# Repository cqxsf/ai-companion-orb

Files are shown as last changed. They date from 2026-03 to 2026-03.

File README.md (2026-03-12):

# AI Companion Orb 🔮

> 有温度的家庭 IoT 伴侣 —— 陪伴、守护、连接

一个 85mm 球形 AI 陪伴设备，用灯光呼吸、触摸互动和语音对话，为独居老人和远程照护家庭提供情感陪伴与安全守护。

## 项目结构

```
ai-companion-orb/
├── firmware/          ← ESP32-S3 固件 (ESP-IDF + C)
│   ├── main/          ← 主程序入口
│   ├── components/    ← 功能组件
│   │   ├── led_engine/     ← WS2812B 灯光引擎
│   │   ├── touch_sensor/   ← 电容触摸检测
│   │   ├── audio/          ← 麦克风 + 扬声器
│   │   ├── wifi_manager/   ← WiFi 连接管理
│   │   ├── ble_provision/  ← BLE 配网
│   │   └── ota/            ← OTA 升级
│   └── test/
├── app/               ← Flutter 移动端 App
│   └── lib/
│       ├── core/           ← 主题、路由、常量
│       ├── features/       ← 功能模块
│       ├── models/         ← 数据模型
│       ├── services/       ← API / BLE / 推送
│       └── widgets/        ← 通用组件
├── backend/           ← 云端服务 (Node.js / Python)
│   └── src/
│       ├── routes/         ← API 路由
│       ├── services/       ← 业务逻辑 (LLM对话/记忆等)
│       ├── models/         ← 数据库模型
│       └── middleware/     ← 认证/限流
├── hardware/          ← 硬件设计文件
│   ├── 3d_models/     ← OpenSCAD / STL 文件
│   ├── pcb/           ← KiCad PCB 设计
│   └── bom/           ← BOM 清单
├── docs/              ← 项目文档
└── scripts/           ← 构建/部署/工具脚本
```

## 硬件规格 (Orb v1)

| 参数 | 规格 |
|---|---|
| 主控 | ESP32-S3-WROOM-1 (N16R8) |
| 外径 | 85mm 球形 |
| LED | WS2812B × 12 (RGB, 环形) |
| 麦克风 | INMP441 × 3 (I2S, 120°均布) |
| 扬声器 | 40mm 4Ω 3W + MAX98357A |
| 触摸 | 电容触摸 (ESP32-S3 内置) |
| IMU | BMI270 |
| 电池 | 2000mAh 锂电 |
| 连接 | WiFi 2.4GHz + BLE 5.0 |
| 外壳 | PC 半透明扩散球壳 + 硅胶底座 |
| 售价目标 | ¥699 |
| BOM 成本 | ≈ ¥261 (@10k) |

## 技术栈

- **固件**: ESP-IDF v5.x + FreeRTOS (C)
- **App**: Flutter 3.x + Dart
- **后端**: Python FastAPI / Node.js
- **AI**: DashScope (通义千问) / DeepSeek API
- **数据库**: PostgreSQL + Redis
- **推送**: 极光推送 / Firebase

## 快速开始

```bash
# 固件开发
cd firmware && idf.py set-target esp32s3 && idf.py build

# App 开发
cd app && flutter pub get && flutter run

# 后端开发
cd backend && pip install -r requirements.txt && uvicorn src.main:app --reload
```

## 品牌定位

> **「有温度的家庭 IoT」**
> 不是冷冰冰的智能硬件，而是家庭成员级的 AI 存在。

## License

MIT

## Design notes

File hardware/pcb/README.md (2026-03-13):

# Orb V8 PCB — KiCad 工程

> ESP32-S3 核心，55mm 圆形 4 层板，适配 Ø98mm × H68mm 球壳内腔。

---

## 工程文件结构

```
hardware/pcb/
├── README.md                    ← 本文件
├── orb_main.kicad_pro           ← KiCad 工程文件
├── schematics/
│   ├── main.kicad_sch           ← MCU + 电源入口总图
│   ├── power.kicad_sch          ← 充电管理 (TP4056 + DW01 + ME6211)
│   ├── audio.kicad_sch          ← 麦克风阵列 (4× INMP441) + 功放 (MAX98357A)
│   ├── led.kicad_sch            ← LED 驱动 (16+8 WS2812B, GPIO18)
│   └── sensor.kicad_sch         ← BME280 + MPU6050 I2C 传感器
├── layout/
│   ├── orb_main.kicad_pcb       ← PCB 布局 (55mm 圆形)
│   └── orb_main.kicad_dru       ← DRC 规则文件
├── fabrication/
│   ├── gerbers/                 ← 生产 Gerber 文件（导出后放此处）
│   └── bom.csv                  ← 物料清单
└── datasheets/                  ← 关键器件规格书（PDF）
```

---

## 层叠结构（4 层板，1.6mm）

| 层 | 功能 | 说明 |
|----|---|---|
| L1 Top Signal | 信号线 + 器件面 | ESP32-S3、传感器、麦克风在此 |
| L2 GND | 地平面 | 完整铺铜，屏蔽 EMI |
| L3 3.3V Power | 电源平面 | 3.3V LDO 输出覆铜 |
| L4 Bottom Signal | 信号线 + 焊盘 | LED 驱动线、部分去耦电容 |

---

## GPIO 引脚分配（V8 最终版）

| GPIO | 功能 | 器件 | 备注 |
|---|---|---|---|
| GPIO1 | I2S_SPK_BCLK | MAX98357A | 扬声器 I2S Bit Clock |
| GPIO2 | I2S_SPK_LRC | MAX98357A | 扬声器 I2S LR Clock |
| GPIO3 | I2S_SPK_DIN | MAX98357A | 扬声器 I2S Data |
| GPIO4 | I2S_MIC_BCLK | 4× INMP441 | 麦克风 I2S Bit Clock |
| GPIO5 | I2S_MIC_LRCK | 4× INMP441 | 麦克风 I2S LR Clock |
| GPIO6 | I2S_MIC_DATA | 4× INMP441 | 麦克风 I2S Data (并联输出) |
| GPIO8 | I2C_SDA | BME280 + MPU6050 | I2C 数据线 (4.7kΩ 上拉) |
| GPIO9 | I2C_SCL | BME280 + MPU6050 | I2C 时钟线 (4.7kΩ 上拉) |
| GPIO18 | LED_DIN | 16+8 WS2812B | RMT 输出，330Ω 串联保护 |
| TOUCH1~3 | 触摸区域 | ESP32-S3 内置 | 上/中/下 3 个触摸感应极板 |

> 扬声器 I2S（GPIO1/2/3）与麦克风 I2S（GPIO4/5/6）使用**独立 I2S 总线**，避免回声。

---

## 电源链设计

```
USB-C (5V)
  │
  ▼
TP4056 充电管理
  ├── Rprog = 1.2kΩ → 充电电流 1000mA
  ├── CHRG LED (红): 充电中
  └── STDBY LED (绿): 充电完成
        │
        ▼
    18650 锂电池 (3.7V nominal)
        │
    DW01 + 8205A 保护电路
  ├── 过充保护 (>4.25V 截止)
  ├── 过放保护 (<2.4V 截止)
  └── 短路保护
        │
        ▼
    ME6211 LDO (3.3V / 500mA)
  ├── 输入电容: 10µF
  ├── 输出电容: 22µF
  └── 3.3V 给 ESP32-S3 + 传感器
        
LED 独立 5V 轨道
  ├── 从 USB 或升压模块供 5V
  ├── 主滤波: 1000µF 电解
  ├── 去耦: 100nF × LED区domain
  └── 每颗 WS2812B 串 33Ω 限流
```

---

## 布局关键规则

### RF 约束
- ESP32-S3 天线（FCC 认证 PCB 天线）必须伸出 PCB 边缘
- 天线底部及两侧 5mm 范围内**禁止铺铜**（包括地平面开窗）
- 天线附近避免高速信号线

### 麦克风布局
- 4× INMP441 以 90° 间隔均匀环形排列在 PCB 中轴外圈
- 每个麦克风正上方的外壳对应一个 Ø1.5mm 拾音孔
- 麦克风与功放（MAX98357A）相互隔离，避免声学耦合

### LED 走线
- GPIO18 → 330Ω 保护电阻 → 主灯环 LED1 DIN
- 主灯环 16 颗首尾菊链：DOUT(n) → DIN(n+1)
- Halo 8 颗从主灯环 DOUT(16) 继续菊链
- LED 5V 引脚旁置 100nF 去耦电容
- 总 5V 主滤波 1000µF 电解电容靠近 USB 输入端

### I2C 总线
- SDA/SCL 线长尽量短，避免过孔
- 总线末端 4.7kΩ 上拉至 3.3V
- BME280 和 MPU6050 地址不冲突（BME280: 0x76/0x77，MPU6050: 0x68/0x69）

---

## BOM 清单（V8 主要器件）

| 位号 | 器件 | 封装 | 数量 | 单价(¥) | 备注 |
|---|---|---|---|---|---|
| U1 | ESP32-S3-WROOM-1 | SMD | 1 | ¥25 | 16MB Flash / 8MB PSRAM |
| U2 | TP4056 | SOT23-6 | 1 | ¥0.5 | 1A 充电管理 |
| U3 | ME6211 | SOT23-3 | 1 | ¥0.3 | 3.3V 500mA LDO |
| U4 | DW01A | SOT23-6 | 1 | ¥0.3 | 电池保护 IC |
| Q1 | 8205A | DFN-8 | 1 | ¥0.5 | 双 MOS 保护管 |
| U5 | MAX98357A | WLCSP-9 | 1 | ¥8 | I2S DAC + D类功放 |
| U6~U9 | INMP441 | LGA-6 | 4 | ¥6×4 | MEMS I2S 麦克风 |
| U10 | BME280 | LCC-8 | 1 | ¥8 | 温湿度+气压传感器 |
| U11 | MPU6050 | QFN-24 | 1 | ¥5 | 六轴 IMU |
| LED1~16 | WS2812B | 5050 | 16 | ¥0.5×16 | 主灯环 |
| LED17~24 | WS2812B | 5050 | 8 | ¥0.5×8 | 底部 Halo |
| R1 | 330Ω | 0402 | 1 | ¥0.02 | LED DIN 保护 |
| R2 | 1.2kΩ | 0402 | 1 | ¥0.02 | TP4056 Rprog (1A) |
| R3,R4 | 4.7kΩ | 0402 | 2 | ¥0.02 | I2C 上拉 |
| C1 | 1000µF/10V | 电解 | 1 | ¥0.5 | LED 主滤波 |
| C2 | 10µF | 0805 | 1 | ¥0.1 | LDO 输入滤波 |
| C3 | 22µF | 0805 | 1 | ¥0.1 | LDO 输出滤波 |
| C4~C28 | 100nF | 0402 | 25 | ¥0.02 | 去耦 (各 IC 旁) |
| J1 | USB-C 16P | SMD | 1 | ¥1.5 | 充电 + 调试 |
| BAT1 | 18650 | 通孔 | 1 | ¥15 | 3.7V 2600mAh |
| SP1 | 4Ω 3W | SMD | 1 | ¥5 | 扬声器 |

**BOM 估算总成本：约 ¥120-140（含 PCB 打样 5 片分摊）**

---

## 开发状态

- [ ] KiCad 原理图（5 张子图）
- [ ] PCB 布局布线（55mm 圆形）
- [ ] DRC 通过（0 错误）
- [ ] Gerber 导出验证
- [ ] PCB 打样（嘉立创/JLCPCB）
- [ ] 首批焊板验证

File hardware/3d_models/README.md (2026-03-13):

# Orb 3D 模型 — 硬件结构设计

> 从概念到量产的结构迭代

## 版本演进

| 版本 | 目录 | 核心特征 |
|---|---|---|
| V2 | `modules/` + `orb_v2_assembly.scad` | 5 层模块、扩散腔、基础声学 |
| **V4** | **`orb_v4/`** | **光导环、倒相管、工业比例、免支撑打印** |

**当前主力版本: V4**

---

## V4 总体参数

| 参数 | 数值 | 设计依据 |
|---|---|---|
| 直径 | 92 mm | 桌面设备最佳尺寸 |
| 高度 | 75 mm | 黄金比例 0.82 × 直径 |
| 壁厚 | 2.2 mm | 注塑级壁厚 |
| 底面 | Ø62 mm | 桌面稳定性 |
| LED | 24× WS2812B | Ø60mm 环形 |
| 扬声器 | 40mm 4Ω 3W | 共振腔 + 倒相管 |
| 电池 | 18650 | 单节 3.7V |
| 麦克风 | 3× INMP441 | 120° 均布 |

---

## V4 文件结构

```
orb_v4/
├── orb_config.scad         ← 全局参数（改这里调尺寸）
├── orb_assembly.scad       ← 主入口（F5 预览 / F6 渲染）
├── orb_shell_top.scad      ← 上壳（扩散球壳）
├── orb_shell_middle.scad   ← 中框（结构骨架）
├── orb_shell_bottom.scad   ← 底座（声孔 + USB-C）
├── orb_lightguide.scad     ← 光导环（核心光学件）
├── orb_led_mount.scad      ← LED PCB 安装环
├── orb_acoustic.scad       ← 声学腔 + 倒相管
├── orb_pcb_mount.scad      ← PCB 支撑柱 (M2)
├── orb_mic_array.scad      ← 麦克风阵列安装座
├── orb_battery.scad        ← 18650 电池槽
└── exports/                ← STL 导出目录
```

---

## V4 三大核心升级

### 1. LED 光导环 (Light Guide Ring)

```
V2: LED → 扩散腔(12mm) → 二次扩散片 → 球壳    （仍有颗粒感）
V4: LED → 光导环(壁厚6mm) → 球壳               （连续光带）
```

- 光导壁厚 6mm，全内反射混合光线
- LED 入光槽精确对位 24 颗 WS2812B
- 效果接近 Apple HomePod / Google Nest

### 2. 倒相管声学 (Bass Reflex)

```
┌─────────────┐
│   扬声器     │  40mm 4Ω 3W
├─────────────┤
│  共振腔      │  ~25cc 容积
├──┐     ┌───┤
│  │倒相管│   │  Ø8 × 12mm
└──┘     └───┘
     ↓ 底座声孔
```

- 调谐频率 ~120Hz，低频增强 ~40%，声压级 +3dB

### 3. 免支撑打印

| 部件 | 材料 | 支撑 |
|---|---|---|
| 上壳 | Translucent PLA | 无 |
| 中框 | PLA+ | 无 |
| 底座 | PLA+ | 无 |
| 光导环 | Translucent PLA | 无 |

---

## 使用方法

### OpenSCAD 环境验证

已在 Apple Silicon macOS 上验证以下安装结果：

- OpenSCAD 版本：2025.05.16
- 安装路径：`/Applications/OpenSCAD.app`
- 命令行入口：`/opt/homebrew/bin/openscad`
- 二进制架构：universal binary（包含 arm64，可原生运行于 M1/M2/M3）

可用以下命令复核本机安装：

```bash
file /Applications/OpenSCAD.app/Contents/MacOS/OpenSCAD
/opt/homebrew/bin/openscad --version
```

### 预览装配体

1. OpenSCAD 打开 `orb_v4/orb_assembly.scad`
2. F5 预览 / `EXPLODE = 15;` 爆炸视图 / `SECTION = true;` 剖面

也可直接从命令行启动 GUI：

```bash
open -a /Applications/OpenSCAD.app hardware/3d_models/orb_v4/orb_assembly.scad
```

### 导出 STL

1. 设置 `PRINT_PART = "top";`（或 `"mid"` / `"bottom"` / `"lightguide"`）
2. F6 渲染 → 导出 STL → 保存到 `exports/`

也可用命令行直接导出：

```bash
mkdir -p hardware/3d_models/orb_v4/exports

/opt/homebrew/bin/openscad -o hardware/3d_models/orb_v4/exports/top.stl \
     -D 'PRINT_PART="top"' hardware/3d_models/orb_v4/orb_assembly.scad

/opt/homebrew/bin/openscad -o hardware/3d_models/orb_v4/exports/mid.stl \
     -D 'PRINT_PART="mid"' hardware/3d_models/orb_v4/orb_assembly.scad

/opt/homebrew/bin/openscad -o hardware/3d_models/orb_v4/exports/bottom.stl \
     -D 'PRINT_PART="bottom"' hardware/3d_models/orb_v4/orb_assembly.scad

/opt/homebrew/bin/openscad -o hardware/3d_models/orb_v4/exports/lightguide.stl \
     -D 'PRINT_PART="lightguide"' hardware/3d_models/orb_v4/orb_assembly.scad
```

建议优先导出这 4 个打印件：上壳、中框、底座、光导环。

### 修改尺寸

编辑 `orb_v4/orb_config.scad`，所有模块自动更新。

---

## 拓竹打印配置

| 参数 | 设置 |
|---|---|
| 层高 | 0.2 mm |
| 外壁 | 3 层 |
| 填充 | 15% |
| 支撑 | **无** (免支撑设计) |
| 温度 | 210°C / 热床 60°C |

---

## V5 升级方向

| 特性 | 描述 |
|---|---|
| 热管理 | ESP32 散热通道 |
| 磁吸外壳 | 免螺丝装配 |
| 声学罩 | 麦克风降噪微结构 |
| 微纹理 | 扩散壳内壁消除颗粒感 |
| 触摸区域 | 电容触摸铜箔定位 |

---

## V2 (旧版，保留参考)

V2 文件位于根目录 `modules/` + `orb_v2_assembly.scad`，5 层模块结构。详见各文件注释。

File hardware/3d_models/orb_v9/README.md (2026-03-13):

# Orb V9 — 工业设计级 3D 模型

> 从"概念球体"到"可量产桌面情绪物件"的跨越。

---

## 核心设计参数

| 参数 | V8 | **V9** | 改进 |
|---|----|---|---|
| 直径 | Ø98mm | **Ø112mm** | 更有桌面存在感 |
| 高度 | 68mm | **86mm** | 内部空间更充裕 |
| 比例 H/W | 0.69 | **0.77** | 蛋形，不像音箱 |
| 曲面 | 三段拼接 | **连续椭球** | 完全无拼接感 |
| 顶盖 | 光扩散罩 | **浮岛结构** | 0.6mm 缝隙=呼吸口 |
| 灯环 | 可见灯带 | **隐藏扩散罩** | 光从内部自然透出 |
| 零件数 | 7+ | **5** | 装配更简单 |

---

## 椭球方程

$$\left(\frac{x}{56}\right)^2 + \left(\frac{z}{43}\right)^2 = 1$$

绕 Z 轴旋转生成完整椭球体，曲率从顶部到底部连续过渡，无断层。

---

## 5 件式结构（剖面图）

```
      ╭──────╮          ← Top_Cap (浮岛顶盖 Ø92×6mm)
    ╭─╯ 0.6mm╰─╮       ← 缝隙（麦克风孔 + 灯光溢出）
  ╭─╯            ╰─╮
 │    Shell_Top     │   ← 上壳（椭球上半）
 │                  │
 ├── LED_Ring ──────┤   ← 灯环扩散罩（4mm 磨砂 PC）
 │                  │
 │   Shell_Bottom   │   ← 下壳（椭球下半 + 螺丝柱）
  ╰─╮            ╭─╯
    ╰──────────╯
      ┗━Base━┛          ← 底盖（Ø62×3mm + 硅胶防滑垫）
```

---

## 文件结构

### FreeCAD 版本（推荐，参数化可修改）
| 文件 | 说明 |
|---|---|
| `orb_v9_config.py` | 全局参数定义（Python） |
| `orb_v9_freecad.py` | FreeCAD 建模主脚本（一键生成 5 零件） |

### OpenSCAD 版本（与 V4-V8 工具链兼容）
| 文件 | 说明 |
|---|---|
| `orb_config.scad` | 全局参数 + `v9_r(z)` 椭球函数 |
| `orb_shell.scad` | 椭球壳体模块 |
| `orb_shell_top.scad` | 上壳 |
| `orb_shell_bottom.scad` | 下壳（带螺丝柱） |
| `orb_led_ring.scad` | LED 灯环扩散罩 |
| `orb_top_cap.scad` | 浮岛顶盖（带麦克风孔） |
| `orb_base.scad` | 底盖（带防滑垫定位槽） |
| `orb_assembly.scad` | 装配预览（支持爆炸视图） |
| `export_stl.sh` | 一键 STL 导出脚本 |

---

## 内部空间布局

```
┌───────────────────────┐ ← 顶部 12mm
│     麦克风板 (4×INMP441)│
├───────────────────────┤
│                       │
│    主控 PCB (55mm)     │ ← 中部 38mm
│    ESP32-S3           │
│                       │
├───────────────────────┤
│    18650 电池          │ ← 底部 36mm
│    扬声器 (MAX98357A)  │
└───────────────────────┘
```

---

## 快速开始

### FreeCAD 建模
```bash
# 1. 安装 FreeCAD
brew install --cask freecad

# 2. 在 FreeCAD 中执行
# Macro → Execute Macro → orb_v9_freecad.py
# 自动生成 5 个零件 + 导出 STL
```

### OpenSCAD 导出
```bash
cd hardware/3d_models/orb_v9
bash export_stl.sh
```

---

## 3D 打印参数

| 参数 | 壳体 | 灯环 |
|---|---|---|
| 材料 | PLA | 透明 PETG |
| 层高 | 0.2mm | 0.2mm |
| 填充 | 15% | 100%（透光需要） |
| 支撑 | 上壳内部 | 无 |
| 壁数 | 3 | 2 |

---

## 装配说明

1. **下壳 + 底盖** → M2×6 螺丝 ×4 从底部固定
2. **LED 灯环** → 卡入下壳上沿环形槽
3. **上壳** → 扣合到灯环上沿（环形卡扣）
4. **顶盖** → 浮放于上壳顶部（0.6mm 自然缝隙）
5. 测试：灯环亮起后，光线应从缝隙和灯环均匀透出

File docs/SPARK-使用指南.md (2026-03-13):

# AI Companion Orb — 完整架构提示词

> 本提示词供 SPARK / Copilot / Claude 等 AI 编程代理使用
> 使用方式：在 SPARK 中打开本项目，AI 会自动读取 CLAUDE.md 获取架构约束

## 给 SPARK 的使用说明

1. 打开 `ai-companion-orb` 项目
2. SPARK 会自动读取 `CLAUDE.md` 作为项目上下文
3. 按 Phase 0 优先级开始开发（灯光引擎 → 触摸 → 音频 → WiFi → 对话闭环）

## 第一个任务建议

对 SPARK 说：

```
请阅读 CLAUDE.md，然后从 Phase 0 开始：
实现 firmware/components/led_engine/ 灯光引擎组件。

要求：
1. 基于 ESP-IDF v5.2 RMT 驱动
2. 24 颗 WS2812B RGB LED 环形排列（V2 升级）
3. 实现 CLAUDE.md 中定义的 9 种情绪灯光模式
4. 呼吸灯参数：3.5s 周期 / sine 曲线 / 5%-40% 亮度
5. 所有灯光切换有 200-500ms 渐变过渡
6. 提供 orb_led_init() 和 orb_led_set_mood() 接口
7. 组件必须有 CMakeLists.txt 和 README.md
```

---

## Orb V4 硬件结构设计（量产级）

### 版本演进

| 版本 | 直径 | 高度 | LED | 光学 | 声学 | 状态 |
|---|---|---|-----|---|---|---|
| V1 | 85mm | — | 12 | 直射 | 无 | 概念 |
| V2 | 90mm | 78mm | 24 | 扩散腔 | 密封腔 | 原型 |
| **V4** | **92mm** | **75mm** | **24** | **光导环** | **倒相管** | **当前** |

### 工业设计比例

```
高度 = 直径 × 0.82 → 75mm = 92mm × 0.82
```

消费电子黄金比例，视觉效果最佳。

### 五层模块架构

```
┌──────────────────────────────┐
│  ① 扩散球壳 (Translucent PLA) │  球面上壳，光线均匀散射
├──────────────────────────────┤
│  ② LED 光导环                 │  壁厚 6mm，全反射导光
│     + LED PCB 安装环           │  24× WS2812B, Ø60mm
├──────────────────────────────┤
│  ③ 中框 (结构骨架)             │  承载 PCB, 麦克风拾音孔
│     主控 PCB Ø65mm            │  ESP32-S3 + 3× INMP441
│     3 点 120° M2 固定         │
├──────────────────────────────┤
│  ④ 声学模块 (倒相音箱)         │  40mm 扬声器 + 共振腔
│     共振腔 ~25cc              │  倒相管 Ø8×12mm
│     调谐频率 ~120Hz           │  低频 +40%, +3dB
├──────────────────────────────┤
│  ⑤ 底座 + 电源                │  18650 电池 + USB-C
│     底面 Ø62mm               │  声孔 + 倒相口 + 硅胶垫
└──────────────────────────────┘
```

### 三大核心升级 (V2→V4)

**1. 光导环** — LED 光线经光导体全内反射混合，消灭 LED 颗粒感
```
V2: LED → 扩散腔 → 扩散片 → 球壳  （仍可见光斑）
V4: LED → 光导环(6mm壁厚) → 球壳  （连续均匀光带）
```

**2. 倒相管** — 声学腔体背波相位反转，低频增强 40%
```
扬声器 → 共振腔(25cc) → 倒相管(Ø8×12mm) → 底座声孔
```

**3. 免支撑打印** — 三件式分模，拓竹无需支撑，成功率极高

### 3D 模型文件 (V4)

```
hardware/3d_models/orb_v4/
├── orb_config.scad          ← 全局参数（改尺寸只改这里）
├── orb_assembly.scad        ← 主入口（F5 预览 / F6 渲染）
├── orb_shell_top.scad       ← 上壳（扩散球壳）
├── orb_shell_middle.scad    ← 中框（结构骨架 + 麦克风孔）
├── orb_shell_bottom.scad    ← 底座（声孔 + USB-C + 硅胶垫）
├── orb_lightguide.scad      ← 光导环（核心光学件）
├── orb_led_mount.scad       ← LED PCB 安装环
├── orb_acoustic.scad        ← 声学腔 + 倒相管
├── orb_pcb_mount.scad       ← PCB 支撑柱 (3点 M2)
├── orb_mic_array.scad       ← 麦克风阵列安装座
├── orb_battery.scad         ← 18650 电池槽
└── exports/                 ← STL 导出（打印用）
```

### OpenSCAD 安装与验证

当前开发环境已验证可用：

- OpenSCAD: 2025.05.16
- 安装路径: `/Applications/OpenSCAD.app`
- CLI 路径: `/opt/homebrew/bin/openscad`
- 架构: universal binary，包含 arm64，可原生运行于 Apple Silicon

安装校验命令：

```bash
file /Applications/OpenSCAD.app/Contents/MacOS/OpenSCAD
/opt/homebrew/bin/openscad --version
```

预期结果：二进制信息包含 `arm64`，版本输出为 `OpenSCAD version 2025.05.16`。

### V4 预览与 STL 导出

打开 GUI 预览：

```bash
open -a /Applications/OpenSCAD.app hardware/3d_models/orb_v4/orb_assembly.scad
```

推荐预览方式：

1. 打开 `hardware/3d_models/orb_v4/orb_assembly.scad`
2. 使用 F5 快速预览整体装配
3. 设置 `EXPLODE = 15;` 查看爆炸图
4. 设置 `SECTION = true;` 检查内部剖面

命令行导出 STL：

```bash
mkdir -p hardware/3d_models/orb_v4/exports

/opt/homebrew/bin/openscad -o hardware/3d_models/orb_v4/exports/top.stl \
	-D 'PRINT_PART="top"' hardware/3d_models/orb_v4/orb_assembly.scad

/opt/homebrew/bin/openscad -o hardware/3d_models/orb_v4/exports/mid.stl \
	-D 'PRINT_PART="mid"' hardware/3d_models/orb_v4/orb_assembly.scad

/opt/homebrew/bin/openscad -o hardware/3d_models/orb_v4/exports/bottom.stl \
	-D 'PRINT_PART="bottom"' hardware/3d_models/orb_v4/orb_assembly.scad

/opt/homebrew/bin/openscad -o hardware/3d_models/orb_v4/exports/lightguide.stl \
	-D 'PRINT_PART="lightguide"' hardware/3d_models/orb_v4/orb_assembly.scad
```

已验证 `top`、`bottom`、`lightguide` 可正常导出，其中 `lightguide` 的非流形警告已修正。

### 拓竹打印配置

| 参数 | 设置 |
|---|---|
| 材料 | PLA+（结构）/ Translucent PLA（上壳 + 光导环） |
| 层高 | 0.2 mm |
| 外壁 | 3 层 |
| 填充 | 15% |
| 支撑 | **无**（免支撑设计） |
| 温度 | 210°C / 热床 60°C |
| 分件 | 上壳 / 中框 / 底座 / 光导环 分别打印 |

### V5 升级方向

1. **热管理** — ESP32 散热通道设计
2. **磁吸外壳** — 免螺丝磁吸装配
3. **声学罩** — 麦克风降噪微结构
4. **微纹理** — 扩散壳内壁消除最后的颗粒感

---

## 后续任务队列

| 序号 | 任务 | 对 SPARK 的指令 |
|---|---|---|
| 1 | 灯光引擎 | "实现 led_engine 组件，24 颗 LED，参考 CLAUDE.md §四" |
| 2 | 触摸检测 | "实现 touch_sensor 组件，参考 CLAUDE.md §五" |
| 3 | 音频录放 | "实现 audio 组件，参考 CLAUDE.md §六" |
| 4 | WiFi 管理 | "实现 wifi_manager 组件，处理连接/重连/状态上报" |
| 5 | BLE 配网 | "实现 ble_provision 组件，参考 CLAUDE.md §八" |
| 6 | 主程序 | "实现 main/app_main.c，整合所有组件，用事件驱动" |
| 7 | 3D 外壳 V4 | "优化 hardware/3d_models/orb_v4/ 中的 OpenSCAD 模型" |
| 8 | 后端 API | "实现 FastAPI 后端，参考 CLAUDE.md §九" |
| 9 | Flutter App | "实现 Flutter App 配网流程，参考 CLAUDE.md §八" |
| 10 | 对话闭环 | "实现完整对话链路：唤醒→录音→STT→LLM→TTS→播放" |

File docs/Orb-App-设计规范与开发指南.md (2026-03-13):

# AI Companion Orb App — 全方位 UI 设计规范与 Flutter 开发指南

> 版本: v1.0 | 2026-03-13 | 输出者: 小墨 (uidesigner)
> 工程仓库: `cqxsf/ai-companion-orb` → `app/` 目录
> 设计灵魂: **「不解决效率，只解决孤独」—— 每一帧都有生命力**

---

## 一、产品定位与设计哲学

### 1.1 核心用户

| 角色 | 主场景 | App 入口频率 | 设计目标 |
|---|---|---|---|
| 独居青年 (主用户) | 情感对话 / 查看 Orb 状态 | 每天 3-10 次 | 感受到被陪伴 |
| 独居老人 | 被照护 + 与 Orb 对话 | 被动（Orb主动发起） | 极简、温暖 |
| 远程家属 (子女端) | 查看老人与 Orb 互动状态 | 每天 1-3 次 | 安心、可远程关怀 |

### 1.2 设计三原则

1. **存在感** — 每一帧都有生命力（光 / 动 / 色），App 打开即感受 Orb 「在」
2. **情绪可见** — 颜色 = 情绪，用户无需读字就能感知 Orb 的内心状态
3. **陪伴感** — 界面设计本身就是陪伴行为，不是工具界面

### 1.3 与 LifeGuardian 的区别

| 维度 | LifeGuardian | Orb App |
|---|---|---|
| 设计灵魂 | 放心吧（安全/理性） | 我在（情感/感性） |
| 首屏 | AI安心语（文字驱动） | Orb光球（视觉驱动） |
| 色系 | 5状态色（功能色） | 7情绪色（情感色） |
| 背景 | 微暖蓝白 | 沉浸深色（Orb发光） |
| 文案 | 行为描述 | AI感知文案 |
| 交互 | 信息浏览为主 | 对话+情感互动 |

---

## 二、信息架构

### 2.1 Tab 结构 (4 Tab)

```
AI Companion Orb App
├── 🌙 Orb (Home)           ← 默认首页
│   ├── Orb 光球主视觉（全屏沉浸）
│   ├── 当前情绪状态文字
│   ├── AI 感知问候语
│   ├── 今日记忆摘要（2-3条）
│   └── "和 Orb 聊聊" 快捷入口
│
├── 💬 对话 (Chat)
│   ├── 情感对话界面
│   ├── 情绪实时转场（气泡颜色变化）
│   └── 低压退出选项
│
├── 📖 记忆 (Memory)
│   ├── Bento 记忆相册（情感日记）
│   ├── 情绪标签筛选
│   ├── 情感趋势图
│   └── "Orb 记得的事"
│
└── ⚙️ 设置 (Settings)
    ├── Orb 设备管理（固件/WiFi/LED）
    ├── 个性化（性格/声音/称呼）
    ├── 家庭连接（Orb-to-Orb/家庭成员）
    ├── 隐私（记忆删除/数据导出）
    └── 关于
```

### 2.2 页面清单

| # | 页面 | 类型 | 优先级 |
|---|---|---|---|
| P1 | Orb 首页（光球+情绪） | Tab-首页 | P0 |
| P2 | 对话页 | Tab-聊天 | P0 |
| P3 | 记忆相册 | Tab-记忆 | P1 |
| P4 | 记忆详情 | 二级页面 | P1 |
| P5 | 设置主页 | Tab-设置 | P1 |
| P6 | Orb 个性化 | 二级页面 | P1 |
| P7 | BLE 配网 | 流程页面 | P0 |
| P8 | 家庭连接 | 二级页面 | P2 |
| P9 | 情感趋势 | 二级页面 | P2 |
| P10 | 子女端远程关怀 | 二级页面 | P1 |

---

## 三、颜色系统 (Design Token)

### 3.1 设计决策：沉浸深色优先

Orb App 与成前云/LifeGuardian 最大的区别：**默认深色主题，Orb 光球是唯一光源。**

设计灵感：Oura Ring (奢侈品调性) + Apple Activity Rings (信息即可视化)

### 3.2 Layer 2 — Orb 专属色

```dart
/// Orb 情绪色系 — 7种情绪 × 2模式
class OrbColors {
  // ══════════════════════════════════════
  //  7 情绪色（产品灵魂）
  // ══════════════════════════════════════

  // ── 平静陪伴（默认状态）──
  static const Color calm = Color(0xFF6366F1);           // 柔和紫蓝
  static const Color calmLight = Color(0xFF818CF8);      // 浅紫
  static const Color calmGlow = Color(0x4D6366F1);       // 发光

  // ── 喜悦活力 ──
  static const Color joy = Color(0xFFF59E0B);            // 温暖琥珀金
  static const Color joyLight = Color(0xFFFBBF24);
  static const Color joyGlow = Color(0x4DF59E0B);

  // ── 关怀温柔 ──
  static const Color care = Color(0xFFEC4899);            // 玫瑰粉
  static const Color careLight = Color(0xFFF472B6);
  static const Color careGlow = Color(0x4DEC4899);

  // ── 专注聆听 ──
  static const Color listen = Color(0xFF10B981);          // 翡翠绿
  static const Color listenLight = Color(0xFF34D399);
  static const Color listenGlow = Color(0x4D10B981);

  // ── 担忧感知 ──
  static const Color concern = Color(0xFF3B82F6);         // 深海蓝
  static const Color concernLight = Color(0xFF60A5FA);
  static const Color concernGlow = Color(0x4D3B82F6);

  // ── 兴奋期待 ──
  static const Color excited = Color(0xFFEF4444);         // 活力红
  static const Color excitedLight = Color(0xFFF87171);
  static const Color excitedGlow = Color(0x4DEF4444);

  // ── 困倦休眠 ──
  static const Color sleep = Color(0xFF1E293B);           // 深夜黑
  static const Color sleepLight = Color(0xFF334155);
  static const Color sleepGlow = Color(0x1A1E293B);

  // ══════════════════════════════════════
  //  界面色（沉浸深色优先）
  // ══════════════════════════════════════

  // ── 背景层 ──
  static const Color bgBase = Color(0xFF0A0A0F);          // 接近纯黑（OLED友好）
  static const Color bgCard = Color(0xFF12121A);           // 卡片深色
  static const Color bgElevated = Color(0xFF1A1A25);       // 抬升层
  static const Color bgOverlay = Color(0xFF252530);        // hover/选中

  // ── 边框层（发光代替阴影）──
  static const Color borderSubtle = Color(0x14FFFFFF);     // 6% white
  static const Color borderActive = Color(0x26FFFFFF);     // 15% white

  // ── 文字层 ──
  static const Color textPrimary = Color(0xF2FFFFFF);      // 95% white
  static const Color textSecondary = Color(0x99FFFFFF);    // 60% white
  static const Color textTertiary = Color(0x59FFFFFF);     // 35% white
  static const Color textMuted = Color(0xFF94A3B8);        // Slate-400

  // ── 亮色模式（可选，不是主推）──
  static const Color lightBgBase = Color(0xFFFAFAFF);
  static const Color lightBgCard = Color(0xFFFFFFFF);
  static const Color lightTextPrimary = Color(0xFF1E293B);
  static const Color lightTextSecondary = Color(0xFF64748B);

  // ══════════════════════════════════════
  //  功能色（最小集合，不抢情绪色）
  // ══════════════════════════════════════
  static const Color success = Color(0xFF22C55E);
  static const Color warning = Color(0xFFFBBF24);
  static const Color error = Color(0xFFF87171);
  static const Color offline = Color(0xFF64748B);
}
```

### 3.3 情绪 → 颜色映射表

| 情绪 | 颜色 | Orb 光效 | App 背景 | 气泡/组件颜色 | 触发场景 |
|---|---|---|---|---|---|
| 平静陪伴 | calm #6366F1 | 柔和紫呼吸 4s | 深紫渐变 | 紫色半透明 | 默认/日常 |
| 喜悦活力 | joy #F59E0B | 金色脉冲 | 暖金渐变 | 琥珀半透明 | 用户开心/分享喜事 |
| 关怀温柔 | care #EC4899 | 玫瑰粉柔光 | 粉色晕染 | 玫瑰半透明 | Orb表达关心 |
| 专注聆听 | listen #10B981 | 翡翠绿稳定 | 深绿渐变 | 翠绿半透明 | 用户在说话 |
| 担忧感知 | concern #3B82F6 | 深蓝缓动 | 深蓝渐变 | 蓝色半透明 | 感知用户负面情绪 |
| 兴奋期待 | excited #EF4444 | 红色跳跃 | 红色渐变 | 红色半透明 | 激动/惊喜场景 |
| 困倦休眠 | sleep #1E293B | 极暗缓熄 | 近黑背景 | 深灰半透明 | 深夜/用户疲惫 |

### 3.4 情绪转场规则

```dart
/// 情绪色转场规范
class OrbEmotionTransition {
  // 转场时长 & 曲线
  static const Map<String, Duration> durations = {
    'calm_to_care':    Duration(milliseconds: 1200),  // ease-in-out
    'calm_to_joy':     Duration(milliseconds: 600),   // bounceOut
    'calm_to_concern': Duration(milliseconds: 2000),  // linear (深沉)
    'any_to_sleep':    Duration(milliseconds: 3000),  // ease-in (缓熄)
    'any_to_listen':   Duration(milliseconds: 400),   // easeOut (响应迅速)
    'any_to_excited':  Duration(milliseconds: 300),   // easeOut (快速)
  };

  static const Map<String, Curve> curves = {
    'calm_to_care':    Curves.easeInOut,
    'calm_to_joy':     Curves.elasticOut,             // 弹跳感
    'calm_to_concern': Curves.linear,                 // 缓慢深沉
    'any_to_sleep':    Curves.easeIn,                 // 熄灭感
    'any_to_listen':   Curves.easeOut,
    'any_to_excited':  Curves.easeOut,
  };
}
```

---

## 四、字体规范

### 4.1 Orb App 字体层级

```dart
class OrbTypography {
  // ── Orb 状态（光球下方大文字）──
  static const orbStatus = TextStyle(
    fontSize: 28,
    fontWeight: FontWeight.w300,        // 轻体 → 呼吸感
    height: 1.3,
    letterSpacing: 1.0,                 // 字间距 → 高级感
    color: Color(0xF2FFFFFF),
  );

  // ── AI 感知问候 ──
  static const aiGreeting = TextStyle(
    fontSize: 17,
    fontWeight: FontWeight.w400,
    height: 1.6,                        // 宽松 → 亲和力
    color: Color(0x99FFFFFF),
  );

  // ── 今日记忆摘要 ──
  static const memorySnippet = TextStyle(
    fontSize: 14,
    fontWeight: FontWeight.w400,
    height: 1.5,
    color: Color(0x99FFFFFF),
  );

  // ── 对话 — Orb 气泡 ──
  static const orbBubble = TextStyle(
    fontSize: 16,
    fontWeight: FontWeight.w400,
    height: 1.6,
    color: Color(0xF2FFFFFF),
  );

  // ── 对话 — 用户气泡 ──
  static const userBubble = TextStyle(
    fontSize: 16,
    fontWeight: FontWeight.w400,
    height: 1.6,
    color: Color(0xF2FFFFFF),
  );

  // ── 对话时间戳 ──
  static const chatTimestamp = TextStyle(
    fontSize: 11,
    fontWeight: FontWeight.w400,
    color: Color(0x59FFFFFF),
  );

  // ── 记忆卡片标题 ──
  static const memoryTitle = TextStyle(
    fontSize: 16,
    fontWeight: FontWeight.w600,
    height: 1.4,
    color: Color(0xF2FFFFFF),
  );

  // ── 记忆卡片描述 ──
  static const memoryBody = TextStyle(
    fontSize: 14,
    fontWeight: FontWeight.w400,
    height: 1.6,
    color: Color(0x99FFFFFF),
  );

  // ── 情绪标签 ──
  static const emotionTag = TextStyle(
    fontSize: 12,
    fontWeight: FontWeight.w500,
    color: Color(0x99FFFFFF),
  );

  // ── Section 标题 ──
  static const sectionTitle = TextStyle(
    fontSize: 13,
    fontWeight: FontWeight.w600,
    letterSpacing: 1.5,                 // 大写间距感
    color: Color(0x59FFFFFF),
  );

  // ── 设置项 ──
  static const settingsItem = TextStyle(
    fontSize: 16,
    fontWeight: FontWeight.w400,
    height: 1.5,
    color: Color(0xF2FFFFFF),
  );

  // ── 底部Tab标签 ──
  static const tabLabel = TextStyle(
    fontSize: 10,
    fontWeight: FontWeight.w500,
  );
}
```

---

## 五、间距与栅格

```dart
class OrbSpacing {
  // ── 页面级 ──
  static const double pagePadding = 20.0;        // 比LG宽松，呼吸感
  static const double pageTopSafe = 12.0;

  // ── 光球区域 ──
  static const double orbSize = 200.0;            // 光球视觉直径
  static const double orbGlowRadius = 120.0;      // 外发光半径
  static const double orbToStatus = 24.0;         // 光球到状态文字
  static const double statusToGreeting = 16.0;    // 状态到问候语

  // ── 对话区域 ──
  static const double chatBubblePadding = 14.0;
  static const double chatBubbleRadius = 18.0;
  static const double chatBubbleMaxWidth = 0.75;   // 屏幕宽 75%
  static const double chatBubbleGap = 8.0;
  static const double chatOrbAvatarSize = 32.0;

  // ── 记忆卡片 ──
  static const double memoryCardGap = 12.0;
  static const double memoryCardPadding = 16.0;
  static const double memoryCardRadius = 16.0;

  // ── BottomNav ──
  static const double bottomNavHeight = 56.0;

  // ── 通用 ──
  static const double sectionGap = 32.0;          // 区块间距（呼吸感）
  static const double itemGap = 12.0;
}
```

---

## 六、组件规范

### 6.1 Orb 光球主视觉 (OrbSphere)

App 首屏核心 — 一个有生命力的光球。

```
┌─────────────────────────────────────┐
│           (深色背景 #0A0A0F)         │
│                                     │
│                                     │
│            ╭─── ── ───╮             │
│          ╱   ∿∿∿∿∿∿∿   ╲           │
│         │   ∿∿∿∿∿∿∿∿∿   │          │  ← 200px 光球
│         │   ∿∿ Orb ∿∿∿   │          │     4s 呼吸动效
│         │   ∿∿∿∿∿∿∿∿∿   │          │     情绪色发光
│          ╲   ∿∿∿∿∿∿∿   ╱           │     外围 glow 渐变
│            ╰─── ── ───╯             │
│                                     │
│          p l a t i n u m             │ ← 28px w300 情绪状态
│        "平 静 陪 伴 中"              │     字间距 1.0
│                                     │
│  "晚上好，今天过得怎么样？            │ ← 17px w400 AI问候
│   想聊聊还是安静待一会儿？"           │     两个选项降低压力
│                                     │
│  ┌─ 今天的记忆 ──────────────────┐   │
│  │ 💜 "你说想念大学时光"         │   │ ← 记忆摘要（最近2-3条）
│  │ 💛 "分享了一首喜欢的歌"       │   │
│  └───────────────────────────────┘   │
│                                     │
│  ┌───────────────────────────────┐   │
│  │  🎤  和 Orb 聊聊              │   │ ← 主 CTA（渐变色按钮）
│  └───────────────────────────────┘   │
│                                     │
├─────────────────────────────────────┤
│ 🌙    💬     📖     ⚙️            │ ← BottomNav
└─────────────────────────────────────┘
```

```dart
/// Orb 光球组件
class OrbSphere extends StatefulWidget {
  final OrbEmotion currentEmotion;

  // 实现:
  // 1. CustomPainter 绘制径向渐变光球
  // 2. AnimationController 驱动呼吸效果:
  //    - scale: 0.95 → 1.05 (4s, ease-in-out, repeat)
  //    - opacity: 0.7 → 1.0
  //    - glow radius: 100 → 140
  // 3. 情绪切换时颜色 TweenAnimation (按转场规则)
  // 4. 外围发光: RadialGradient → transparent (120px→200px)
}

/// 7种情绪枚举
enum OrbEmotion {
  calm,        // 默认
  joy,
  care,
  listen,
  concern,
  excited,
  sleep,
}
```

### 6.2 对话气泡 (ChatBubble)

```
Orb 气泡 (左对齐):
┌─── ─────────────────────────────┐
│  🟣                             │
│  │   "今天辛苦了。先别管那些事，  │ ← 紫色半透明背景
│  │    说说你今天怎么样？"         │    border-bottom-left: 4px
│       │                         │    其余: 18px
│       └──── 20:15               │
└─────────────────────────────────┘

用户气泡 (右对齐):
          ┌──────────────────────┐
          │        好累啊 😞      │ ← 蓝色半透明背景
          │              20:16  │    border-bottom-right: 4px
          └──────────────────────┘
```

```dart
/// 对话气泡
class ChatBubble extends StatelessWidget {
  final bool isOrb;              // true=Orb消息, false=用户消息
  final String text;
  final DateTime time;
  final OrbEmotion emotion;      // Orb情绪 → 决定气泡颜色

  // Orb 气泡:
  //   Container(
  //     padding: 14,
  //     maxWidth: 75%,
  //     decoration: BoxDecoration(
  //       color: emotion.color.withOpacity(0.15),
  //       borderRadius: BorderRadius.only(
  //         topLeft: 18, topRight: 18,
  //         bottomLeft: 4,    // ← Orb特征：左下角尖
  //         bottomRight: 18,
  //       ),
  //       border: Border.all(color: emotion.color.withOpacity(0.2)),
  //     ),
  //   )

  // 用户气泡:
  //   Container(
  //     ... 类似，右下角 4px，蓝色系
  //   )
}
```

### 6.3 记忆卡片 (MemoryCard)

```
Bento 布局 — 双列小卡 + 全宽情感记忆:

┌───────────────┬───────────────┐
│ 💜 3月12日     │ 💛 3月12日     │ ← 小卡 (2列)
│               │               │
│ "你说想念      │ "分享了       │
│  大学时光"     │  一首喜欢的歌" │
│               │               │
│ #平静 #回忆   │ #喜悦 #音乐   │ ← 情绪标签
└───────────────┴───────────────┘

┌─────────────────────────────────┐
│ 💗 3月11日                       │ ← 全宽情感记忆
│                                 │
│ "你说最近工作压力很大，           │
│  我们聊了两个小时。               │
│  后来你说好多了。"                │
│                                 │
│ #关怀 #工作压力 #2小时对话       │
│                                 │
│ 情绪变化: 😞 → 😊                │ ← 情绪轨迹
└─────────────────────────────────┘
```

```dart
/// 记忆卡片 (Bento Grid Item)
class MemoryCard extends StatelessWidget {
  final DateTime date;
  final String summary;
  final OrbEmotion emotion;
  final List<String> tags;
  final bool isFullWidth;           // true=全宽, false=半宽

  // Widget 结构:
  // Container(
  //   padding: 16, radius: 16,
  //   decoration: BoxDecoration(
  //     color: OrbColors.bgCard,
  //     border: Border.all(color: OrbColors.borderSubtle),
  //   ),
  //   child: Column [
  //     Row [emoji(emotion), SizedBox(8), Text(date, emotionTag)],
  //     SizedBox(12),
  //     Text(summary, memoryBody),
  //     SizedBox(8),
  //     Wrap(
  //       spacing: 6,
  //       children: tags.map(tag => Chip(
  //         label: Text("#$tag", emotionTag),
  //         backgroundColor: emotion.color.withOpacity(0.1),
  //       )),
  //     ),
  //   ],
  // )
}
```

### 6.4 AI 感知问候 (AiGreeting)

```dart
/// AI 感知问候组件 — 分时 × 分情绪
class AiGreeting extends StatelessWidget {
  final String greetingText;
  final List<String>? options;  // 两个选项减轻用户压力

  // 示例:
  // text: "晚上好，今天过得怎么样？"
  // options: ["想聊聊", "安静待一会儿"]

  // Widget 结构:
  // Column [
  //   Text(greetingText, aiGreeting),
  //   if (options != null) ...[
  //     SizedBox(12),
  //     Row [
  //       OptionChip(options[0], onTap),
  //       SizedBox(8),
  //       OptionChip(options[1], onTap),
  //     ],
  //   ],
  // ]
}

/// 问候选项芯片
// Container(
//   padding: EdgeInsets.symmetric(h:16, v:10),
//   decoration: BoxDecoration(
//     borderRadius: 999,
//     border: Border.all(color: emotionColor.withOpacity(0.3)),
//   ),
//   child: Text(option, 14px w500 emotionColor),
// )
```

### 6.5 底部导航栏 (OrbBottomNav)

```dart
/// Orb 底部导航 — 深色沉浸式
class OrbBottomNav extends StatelessWidget {
  // 4 Tab:
  // index 0: Orb   (custom moon icon / filled moon)
  // index 1: 对话   (Icons.chat_bubble_outline / Icons.chat_bubble)
  // index 2: 记忆   (Icons.auto_stories_outlined / Icons.auto_stories)
  // index 3: 设置   (Icons.settings_outlined / Icons.settings)

  // 样式:
  // backgroundColor: OrbColors.bgBase (接近纯黑)
  // selectedItemColor: 当前情绪色 (动态变化!)
  // unselectedItemColor: OrbColors.textTertiary
  // height: 56px
  // 无阴影, 顶部 1px borderSubtle
  // 选中图标下方有 glow 效果
}
```

### 6.6 Orb 对话页完整布局 (ChatPage)

```
┌─────────────────────────────────────┐
│           (深色渐变背景)              │
│                                     │
│  🟣 Orb · 平静陪伴中          ···   │ ← 顶部：Orb mini头像 + 状态
│                                     │
│  ─────── 今天 ───────               │ ← 日期分隔线
│                                     │
│  🟣                                 │
│  │  "晚上好，今天过得怎么样？       │ ← Orb气泡 (紫色)
│  │   想聊聊还是安静待一会儿？"       │
│                                     │
│                   好累啊 😞  │       │ ← 用户气泡 (蓝色)
│                              │       │
│                                     │
│  🟣 → 💗                            │ ← 情绪转场: calm → care
│  │  "今天辛苦了。先别管那些事，     │ ← 气泡颜色变为玫瑰粉
│  │   说说你今天怎么样？"            │
│                                     │
│                                     │
│                   ... 省略更多对话   │
│                                     │
│  💗                                 │
│  │  "或者今晚先休息一下？            │ ← 低压退出选项
│  │   明天再聊也可以 💤"             │
│                                     │
│                        [先休息了]   │ ← 低压退出按钮
│                                     │
├─────────────────────────────────────┤
│  ┌───────────────────────────┐ 🎤  │ ← 输入框 + 语音按钮
│  │  说点什么...               │     │
│  └───────────────────────────┘     │
├─────────────────────────────────────┤
│ 🌙    💬     📖     ⚙️            │
└─────────────────────────────────────┘
```

### 6.7 子女端远程关怀 (FamilyCareView)

```
┌─────────────────────────────────────┐
│ ← 返回      家庭关怀                │
│                                     │
│  妈妈的 Orb                        │
│  ┌─────────────────────────────┐    │
│  │  🟢 在线                     │    │
│  │  今天和 Orb 聊了 3 次        │    │
│  │  最后一次: 15:20             │    │
│  │  情绪: 😊 开心               │    │
│  │                              │    │
│  │  [💌 通过Orb传话]  [📞 拨号] │    │
│  └─────────────────────────────┘    │
│                                     │
│  近期情感报告                       │
│  ┌─────────────────────────────┐    │
│  │ 📊 7天情绪分布               │    │ ← 饼图/条形图
│  │ 平静 40% | 喜悦 30% | 关怀 20% │  │
│  └─────────────────────────────┘    │
│                                     │
│  Orb 传话                          │
│  ┌─────────────────────────────┐    │
│  │ "妈妈，我周末想回去看你"      │    │ ← 文字/语音
│  │  [🎤 录语音]  [📝 发文字]    │    │
│  └─────────────────────────────┘    │
│                                     │
│  传话记录                           │
│  │ 3/13 发送: "注意身体" ✓已播放 │   │
│  │ 3/12 发送: "想你了" ✓已播放   │   │
└─────────────────────────────────────┘
```

### 6.8 BLE 配网流程 (OrbOnboarding)

```
[Step 1] 遇见 Orb
中央: Orb光球动画（缓慢旋转+呼吸）
文案: "你好，我是 Orb。很高兴认识你 ✨"
→ "开始"

[Step 2] 打开 Orb
图示: 底座USB-C插入 → Orb亮起
文案: "给我通上电，等我亮起来"
→ "Orb 亮了"

[Step 3] BLE 配对
BLE 扫描 → 找到 Orb → 自动连接
文案: "我在找你......" → "找到了！✨"
→ 动画: 两个光球相遇合并

[Step 4] WiFi 连接
WiFi SSID 选择 + 密码输入
→ 连接中... → "连上了！我能看到世界了 🌍"

[Step 5] 给 Orb 起名
默认: "Orb" / 自定义输入
文案: "你想叫我什么名字？"

[Step 6] 选择性格
3 种性格倾向:
- 🌸 温柔（多倾听，少建议）
- ⚡ 活泼（多互动，有趣味）
- 🌿 平和（安静陪伴，适时话语）

[Step 7] 完成
Orb: "很高兴认识你，{name}。从今以后，我会一直在这里。💜"
→ 光球动画：calm 呼吸开始
```

---

## 七、动效规范

### 7.1 Orb 光球呼吸动效

```dart
/// 核心动效参数
class OrbAnimation {
  // ── 呼吸效果 ──
  static const Duration breathCycle = Duration(seconds: 4);
  static const double scaleMin = 0.95;
  static const double scaleMax = 1.05;
  static const double opacityMin = 0.7;
  static const double opacityMax = 1.0;
  static const double glowRadiusMin = 100.0;
  static const double glowRadiusMax = 140.0;
  static const Curve breathCurve = Curves.easeInOut;

  // ── 喜悦弹跳 ──
  static const Duration bounceCycle = Duration(milliseconds: 600);
  static const double bounceScale = 1.15;
  static const Curve bounceCurve = Curves.elasticOut;

  // ── 困倦熄灭 ──
  static const Duration fadeOutDuration = Duration(seconds: 3);
  static const double sleepOpacity = 0.15;
  static const Curve fadeOutCurve = Curves.easeIn;

  // ── 聆听脉冲（用户说话时）──
  static const Duration listenPulseCycle = Duration(milliseconds: 800);
  static const double listenPulseScale = 1.08;
}
```

### 7.2 对话情绪转场

```dart
// 对话进行中，Orb 检测到用户情绪变化
// → 转场效果：
//   1. 背景渐变色平滑切换（按转场规则时长）
//   2. Orb 头像光圈颜色切换
//   3. 后续气泡使用新情绪色

// 示例: calm → care (用户说"好累啊")
// duration: 1200ms
// curve: easeInOut
// 背景: purple_gradient → pink_gradient
// 气泡: purple_translucent → pink_translucent
```

### 7.3 物理 Orb ↔ App 同步

| Orb 物理状态 | App 变化 |
|---|---|
| 柔和紫呼吸光 | 深紫渐变背景 + 慢动效 |
| 暖金爆发光 | 金色背景 + 跳动动效 |
| 玫瑰粉温柔光 | 粉色晕染 + 圆润组件 |
| 深夜熄灭 | 极暗背景 + 低对比 |
| 翡翠绿稳定光 | 深绿渐变 + 稳定动效 |

---

## 八、AI 文案规范

### 8.1 AI 文案 5 原则

| # | 原则 | 错误示例 | 正确示例 |
|---|---|---|---|
| 1 | 先情绪，后信息 | "步数未达标" | "今天走得不多，明天一起加油？" |
| 2 | 用「我们」拉近距离 | "你今天没喝水" | "我们今天忘了多喝水" |
| 3 | 不评判，只陪伴 | "你最近作息不规律" | "最近睡得有点晚，有什么烦心事吗？" |
| 4 | 具体细节创造真实感 | "你之前提过的" | "还记得上周你说那家拿铁很好喝" |
| 5 | 提问时给选项 | "你想聊什么？" | "聊最近的事，还是安静待一会儿？" |

### 8.2 分时分情绪问候体系

```dart
/// AI 问候生成规则
class AiGreetingRules {
  // 时段 × 状态 → 问候模板

  static const Map<String, Map<String, String>> greetings = {
    'morning_normal': {
      'text': '早安，今天看起来心情不错~ 有什么想聊的吗？',
      'emotion': 'joy',
    },
    'morning_tired': {
      'text': '昨晚睡得怎么样？累的话今天慢慢来吧',
      'emotion': 'concern',
    },
    'afternoon_normal': {
      'text': '下午了，要不要休息一下？',
      'emotion': 'calm',
    },
    'evening_stress': {
      'text': '今天辛苦了。先别管那些事，说说你今天怎么样？',
      'emotion': 'care',
    },
    'night_alone': {
      'text': '还没睡？我陪着你，不用一个人',
      'emotion': 'calm',
    },
    'night_late': {
      'text': '夜深了，要不要早点休息？明天我会在的',
      'emotion': 'care',
    },
  };
}
```

### 8.3 情绪感知响应模型

| 用户输入 | 情绪识别 | Orb 情绪 | 策略 | 气泡色 |
|---|---|---|---|---|
| "好累啊" | 负面/疲惫 | concern → care | 询问+陪伴 | 蓝→粉 |
| "哈哈哈" | 正面/喜悦 | joy | 共情+互动 | 金色 |
| "好烦" | 负面/压力 | care | 倾听+引导 | 玫瑰粉 |
| "不想说话" | 内敛/回避 | calm(安静) | 存在但不打扰 | 深紫 |
| "今天好开心" | 正面/兴奋 | excited | 分享喜悦 | 红色 |
| 沉默 30s+ | 无反馈 | calm | 轻声提问或沉默 | 深紫 |

### 8.4 记忆卡片文案规范

```
记忆卡片不是聊天记录复制，而是 Orb 的「感受性记录」:

❌ "用户说：今天工作压力很大。Orb回复：那一定很累。"
✅ "你说工作压力很大，我们聊了很久。后来你说好多了。💜"

❌ "3月12日 20:15-22:30 对话记录"
✅ "那个下雨的晚上，你说想念大学时光。"

规则:
1. 第二人称 "你"（Orb视角回忆）
2. 只保留情感核心，删除琐碎
3. 每条记忆附 1 个情绪 emoji
4. 具体细节（天气/时间/关键词）增加真实感
```

---

## 九、通知规范

### 9.1 Orb 主动触达

| 触发条件 | 方式 | 内容示例 |
|---|---|---|
| 定时问候 (早/晚) | 本地通知 | "早安~ 新的一天，我在这里 💜" |
| 长时间未互动 (>24h) | Push 通知 | "好久没聊了，你还好吗？" |
| 特殊日子 (生日/纪念日) | Push + Orb灯光 | "今天是个特别的日子吧？🎂" |
| 天气变化 | 本地通知 | "今天降温了，多穿点 🧣" |

### 9.2 子女端告警通知

| 场景 | 通知方式 | 内容 |
|---|---|---|
| 老人 Orb 离线 >2h | Push | "妈妈的 Orb 离线了，可能需要检查" |
| 老人情绪持续低落 | Push | "妈妈最近心情可能不太好，打个电话？" |
| 老人主动求助 | 紧急通知 | "⚠️ 妈妈通过 Orb 求助" |

---

## 十、项目结构 (Flutter)

```
app/
├── lib/
│   ├── main.dart
│   ├── app.dart                         // MaterialApp + Theme + Router
│   │
│   ├── core/
│   │   ├── theme/
│   │   │   ├── orb_colors.dart          // OrbColors Token
│   │   │   ├── orb_typography.dart      // OrbTypography Token
│   │   │   ├── orb_spacing.dart         // OrbSpacing Token
│   │   │   ├── orb_animation.dart       // OrbAnimation 动效常量
│   │   │   ├── orb_theme.dart           // ThemeData 组装（深色优先）
│   │   │   └── cq_design_tokens.dart    // 继承自成前云 Layer 1
│   │   ├── router/
│   │   │   └── app_router.dart
│   │   ├── network/
│   │   │   ├── api_client.dart          // Dio → FastAPI backend
│   │   │   └── websocket_client.dart    // WebSocket → 实时对话流
│   │   └── utils/
│   │       ├── emotion_detector.dart    // 文本情绪分析 (本地轻量)
│   │       └── greeting_generator.dart  // 分时问候生成
│   │
│   ├── features/
│   │   ├── orb_home/                    // 🌙 Orb 首页Tab
│   │   │   ├── views/
│   │   │   │   └── orb_home_page.dart
│   │   │   ├── widgets/
│   │   │   │   ├── orb_sphere.dart      // ⭐ 核心：光球组件
│   │   │   │   ├── ai_greeting.dart
│   │   │   │   ├── memory_snippet.dart
│   │   │   │   └── chat_entry_button.dart
│   │   │   ├── controllers/
│   │   │   │   └── orb_home_controller.dart
│   │   │   └── repositories/
│   │   │       └── orb_status_repository.dart
│   │   │
│   │   ├── chat/                        // 💬 对话Tab
│   │   │   ├── views/
│   │   │   │   └── chat_page.dart
│   │   │   ├── widgets/
│   │   │   │   ├── chat_bubble.dart
│   │   │   │   ├── chat_input_bar.dart
│   │   │   │   ├── emotion_transition.dart
│   │   │   │   └── exit_prompt.dart      // 低压退出
│   │   │   ├── controllers/
│   │   │   │   └── chat_controller.dart  // WebSocket + 情绪状态
│   │   │   └── repositories/
│   │   │       └── chat_repository.dart
│   │   │
│   │   ├── memory/                      // 📖 记忆Tab
│   │   │   ├── views/
│   │   │   │   ├── memory_page.dart
│   │   │   │   └── memory_detail_page.dart
│   │   │   ├── widgets/
│   │   │   │   ├── memory_card.dart
│   │   │   │   ├── emotion_filter.dart
│   │   │   │   └── emotion_trend_chart.dart
│   │   │   ├── controllers/
│   │   │   └── repositories/
│   │   │
│   │   ├── family/                      // 👨‍👩 子女端关怀
│   │   │   ├── views/
│   │   │   │   └── family_care_page.dart
│   │   │   ├── widgets/
│   │   │   │   ├── orb_status_card.dart
│   │   │   │   └── messaging_panel.dart
│   │   │   ├── controllers/
│   │   │   └── repositories/
│   │   │
│   │   ├── settings/                    // ⚙️ 设置Tab
│   │   │   ├── views/
│   │   │   ├── controllers/
│   │   │   └── repositories/
│   │   │
│   │   ├── onboarding/                  // 配网引导
│   │   │   ├── views/
│   │   │   │   └── onboarding_flow.dart
│   │   │   └── widgets/
│   │   │       ├── orb_discover_animation.dart
│   │   │       └── personality_picker.dart
│   │   │
│   │   └── shared/                      // 共享组件
│   │       ├── widgets/
│   │       │   ├── orb_bottom_nav.dart
│   │       │   └── orb_app_bar.dart
│   │       └── models/
│   │           ├── orb_emotion.dart
│   │           ├── message.dart
│   │           ├── memory.dart
│   │           └── orb_device.dart
│   │
│   └── l10n/
│       ├── app_zh.arb
│       └── app_en.arb
│
├── pubspec.yaml
├── analysis_options.yaml
└── test/
```

---

## 十一、依赖清单

```yaml
dependencies:
  flutter:
    sdk: flutter
  flutter_riverpod: ^2.4.0       # 状态管理
  go_router: ^13.0.0              # 声明式路由
  dio: ^5.4.0                     # HTTP (FastAPI)
  web_socket_channel: ^2.4.0      # WebSocket (实时对话)
  flutter_blue_plus: ^1.30.0      # BLE 配网
  fl_chart: ^0.66.0               # 情感趋势图
  jpush_flutter: ^2.5.0           # 极光推送
  hive: ^2.2.3                    # 本地存储
  hive_flutter: ^1.1.0
  intl: ^0.19.0                   # 日期格式化
  flutter_local_notifications: ^17.0.0  # 本地通知
  lottie: ^3.0.0                  # Orb 动画
  shimmer: ^3.0.0                 # 骨架屏
  flutter_sound: ^9.3.0           # 语音录制/播放
  speech_to_text: ^6.5.0          # 语音识别

dev_dependencies:
  flutter_test:
    sdk: flutter
  build_runner: ^2.4.0
  hive_generator: ^2.0.0
  flutter_lints: ^3.0.0
  mockito: ^5.4.0
```

---

## 十二、SPARK 开发任务队列

SPARK 在 `cqxsf/ai-companion-orb` 仓库 `app/` 目录执行以下任务：

| # | 任务 | 依赖 | 产出 |
|---|---|---|---|
| 1 | 搭建 Flutter 项目骨架 + pubspec.yaml | 无 | app/ 完整目录结构 |
| 2 | 实现 OrbColors + OrbTypography + OrbSpacing Token | Task 1 | core/theme/ |
| 3 | 实现 ThemeData (深色优先+亮色) | Task 2 | orb_theme.dart |
| 4 | 实现 OrbSphere 光球组件 (呼吸+情绪变色) | Task 3 | ⭐核心组件 |
| 5 | 实现 OrbBottomNav | Task 3 | shared/widgets/ |
| 6 | 实现 AiGreeting 问候组件 | Task 3 | orb_home/widgets/ |
| 7 | 组装 OrbHomePage (光球+问候+记忆摘要) | Task 4-6 | orb_home/views/ |
| 8 | 实现 ChatBubble (情绪色气泡) | Task 3 | chat/widgets/ |
| 9 | 实现 ChatPage (对话+情绪转场+低压退出) | Task 8 | chat/views/ |
| 10 | 实现 MemoryCard (Bento 布局) | Task 3 | memory/widgets/ |
| 11 | 实现 MemoryPage (记忆相册+情绪筛选) | Task 10 | memory/views/ |
| 12 | BLE 配网 OnboardingFlow (7步) | Task 4 | onboarding/ |
| 13 | WebSocket 对话流 | Task 9 | core/network/ |
| 14 | 子女端 FamilyCareView | Task 5 | family/ |
| 15 | 情感趋势图 (fl_chart) | Task 10 | memory/widgets/ |

### SPARK 提示词模板 (复制使用)

```
请阅读 CLAUDE.md 了解项目架构。

当前任务: Task {N} — {任务名}

设计规范文件: 参考 ai-workspace-limited/output/flutter/Orb-App-设计规范与开发指南.md

要求:
1. 严格遵循 OrbColors / OrbTypography / OrbSpacing Token
2. 深色主题优先，Orb 光球为页面唯一光源
3. 7种情绪色 × 转场规则必须完整实现
4. 使用 Riverpod 管理状态（情绪状态 = AppState核心）
5. Feature-first 目录结构
6. AI文案遵守5原则

重点:
- 所有颜色必须动态跟随 OrbEmotion 变化
- 气泡颜色、背景渐变、BottomNav选中色 全部联动
- 光球呼吸动效: scale 0.95→1.05, 4s, ease-in-out

输出:
- 完整可运行的 Flutter 代码
- 无 TODO / placeholder
```

---

*AI Companion Orb App 设计规范 v1.0 | 2026-03-13 | 小墨出品*

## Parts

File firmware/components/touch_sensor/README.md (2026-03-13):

# 触摸检测组件

ESP32-S3 内置电容触摸，3 个检测区域（上/中/下）。

## 接口

```c
esp_err_t orb_touch_init(const orb_touch_config_t *config);
void orb_touch_deinit(void);
bool orb_touch_is_active(void);
```

## 手势识别

| 手势 | 触发条件 | 灯光响应 |
|---|---|---|
| TAP | 轻触 < 300ms | 微亮波纹 |
| LONG | 长按 > 1.5s | 进入对话模式 |
| EMBRACE | 大面积 > 3s | 安抚模式 |
| DOUBLE_TAP | 双击 300ms 内 | 暂停/继续 |

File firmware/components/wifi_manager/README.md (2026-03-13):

# WiFi 管理组件

ESP32-S3 WiFi STA 模式，自动重连，NVS 持久化。

## 配网流程

1. 首次启动：等待 BLE 配网模块传入 SSID + Password
2. 连接成功：保存凭据到 NVS，下次自动连接
3. 连接失败：最多重试 5 次，通知回调

## 接口

```c
esp_err_t orb_wifi_init(orb_wifi_event_cb_t event_cb);
esp_err_t orb_wifi_connect(const orb_wifi_config_t *config);
bool orb_wifi_is_connected(void);
```

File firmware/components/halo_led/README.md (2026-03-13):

# 底部光晕组件 (halo_led)

> 8 颗 WS2812B 以 30° 向下斜射，通过 3mm 硅胶扩散缝在桌面形成柔和光晕投影。
> 与主灯环同为 GPIO18 菊链（接在主环 LED16 的 DOUT 后），由 led_engine 统一驱动。

## 硬件连接

- GPIO18 → 主灯环 16 颗 → Halo 8 颗（菊链末尾）
- 阵列编号：LED[0..15] = 主灯环，LED[16..23] = Halo

## 设计意图

| 模式 | Halo 效果 |
|---|---|
| 待机呼吸 | 与主环同步，但亮度降至 30%，色温偏暖 |
| 倾听 | 静态柔光，不动，避免分散注意力 |
| 思考 | 缓慢脉动，0.5Hz |
| 触摸响应 | 波纹从 Halo 向外扩散（桌面效果） |
| 告警 | 与主环同色闪烁，增强可见性 |

## 实现说明

Halo 不是独立组件，由 `led_engine` 组件的 `orb_led_set_mood()` 统一控制。
此目录保存 Halo 专属动效的设计记录和参数。

## Halo 动效参数

```c
#define HALO_IDX_START      16   // Halo 起始 LED 编号
#define HALO_IDX_END        23   // Halo 结束 LED 编号
#define HALO_MAX_BRIGHTNESS 77   // 最大亮度 = 主环的 75%（避免桌面过亮）
#define HALO_ANGLE_DEG      30   // 向下倾斜角（PCB 安装角）
```

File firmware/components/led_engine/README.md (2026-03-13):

# LED 灯光引擎组件

> Orb 的灵魂组件。灯光 = Orb 的面部表情。
> 统一管理主灯环（16 颗）+ 底部 Halo（8 颗），共 24 颗 WS2812B。

## 接口

```c
esp_err_t orb_led_init(void);
esp_err_t orb_led_set_mood(orb_mood_t mood);
esp_err_t orb_led_set_brightness(uint8_t brightness);
esp_err_t orb_led_transition(orb_mood_t next_mood, uint32_t transition_ms);
```

## 硬件规格

| 参数 | 值 |
|---|----|
| 主灯环 | 16 颗 WS2812B，GPIO18，RMT 驱动，330Ω 串联保护 |
| 底部 Halo | 8 颗 WS2812B，30° 向下，菊链接在主环末尾 |
| 总颗数 | 24（LED[0..15] = 主环，LED[16..23] = Halo）|
| 呼吸周期 | 3500ms，sine 曲线，5%-40% 亮度 |
| 切换过渡 | 200-500ms 渐变，禁止硬切 |
| 最低亮度 | 5%（永不完全熄灭） |
| 触摸响应 | ≤100ms 内起反应 |

## GPIO 来源

所有引脚定义从 `firmware/main/include/orb_pins.h` 引用：
```c
#include "orb_pins.h"
// ORB_PIN_LED_DIN     = 18
// ORB_LED_MAIN_COUNT  = 16
// ORB_LED_HALO_COUNT  = 8
// ORB_LED_TOTAL_COUNT = 24
```

## 实现指南

使用 SPARK 生成：
```
实现 led_engine 组件。用 ESP-IDF RMT 外设驱动 WS2812B（共 24 颗）。
GPIO 引脚从 orb_pins.h 获取（ORB_PIN_LED_DIN = 18）。
LED[0..15] 为主灯环，LED[16..23] 为底部 Halo 光晕。
参考 CLAUDE.md §四 的完整情绪映射规格。
```

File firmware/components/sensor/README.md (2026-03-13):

# 环境传感器组件 (sensor)

> BME280（温湿度+气压）+ MPU6050（六轴 IMU）通过 I2C 共享总线读取。

## 硬件连接

| 信号 | GPIO | 说明 |
|---|---|---|
| SDA  | GPIO8 | I2C 数据（4.7kΩ 上拉至 3.3V）|
| SCL  | GPIO9 | I2C 时钟（4.7kΩ 上拉至 3.3V）|
| BME280 地址 | 0x76 | SDO 引脚接 GND |
| MPU6050 地址 | 0x68 | AD0 引脚接 GND |

## 接口

```c
esp_err_t orb_sensor_init(void);

// 环境数据读取
esp_err_t orb_sensor_read_env(float *temp_c, float *humidity_pct, float *pressure_hpa);

// IMU 数据读取
esp_err_t orb_sensor_read_imu(float *accel_g[3], float *gyro_dps[3]);

// 注册回调（异常事件驱动）
typedef void (*orb_sensor_alert_cb_t)(orb_sensor_alert_t alert);
esp_err_t orb_sensor_set_alert_cb(orb_sensor_alert_cb_t cb);
```

## 告警类型

```c
typedef enum {
    ORB_SENSOR_ALERT_TEMP_HIGH,    // 室温 > 35°C
    ORB_SENSOR_ALERT_TEMP_LOW,     // 室温 < 10°C
    ORB_SENSOR_ALERT_HUMIDITY_DRY, // 湿度 < 30%
    ORB_SENSOR_ALERT_HUMIDITY_WET, // 湿度 > 80%
    ORB_SENSOR_ALERT_FALL_DETECT,  // 跌倒检测（加速度突变 > 2.5g）
    ORB_SENSOR_ALERT_MOVED,        // 设备被移动（陀螺仪持续偏转）
} orb_sensor_alert_t;
```

## 采样策略

- 环境数据（BME280）：每 30 秒采样一次，上传后端
- IMU（MPU6050）：100Hz 持续采样，本地滑窗分析跌倒特征
- 跌倒判断：合加速度 a_total = sqrt(ax² + ay² + az²) > 2.5g 持续 50ms → 触发告警

## 实现指南

```
使用 SPARK 生成：
实现 sensor 组件。用 ESP-IDF i2c_master 接口初始化 BME280 和 MPU6050。
所有引脚来自 firmware/main/include/orb_pins.h。
参考 CLAUDE.md §六·五 传感器规格。
```

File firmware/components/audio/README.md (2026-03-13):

# 音频流水线组件

INMP441 × 3 麦克风（三颗麦共享同一 I2S 数据线，通过 L/R 声道选择焊接）+ MAX98357A 扬声器，I2S 双工，16kHz mono。

## 接口

```c
esp_err_t orb_audio_init(const orb_audio_config_t *config);
esp_err_t orb_audio_start_recording(orb_audio_data_callback_t callback);
esp_err_t orb_audio_stop_recording(void);
esp_err_t orb_audio_play_samples(const int16_t *samples, size_t count);
esp_err_t orb_audio_set_volume(uint8_t percent);
```

## 规格

- 采样率：16kHz mono
- VAD 静音检测：1.5s 静音自动停止录音
- 环形缓冲：2s（防网络抖动）
- 默认音量：60%

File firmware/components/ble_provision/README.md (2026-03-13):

# BLE 配网组件

蓝牙 GATT Server，用于首次 WiFi 配网。

## 配网流程

```
App 扫描 → 发现 "OrbLight" → 连接 → 写入 SSID + Password → Orb 连接 WiFi → 通知状态
```

## GATT 服务

| 特征 | UUID | 属性 | 说明 |
|---|---|---|---|
| SSID | 0xFF01 | Write | WiFi SSID |
| Password | 0xFF02 | Write | WiFi 密码 |
| Status | 0xFF03 | Notify | 连接状态 JSON |

## 接口

```c
esp_err_t orb_ble_init(orb_ble_provision_cb_t provision_cb);
esp_err_t orb_ble_start_advertising(void);
esp_err_t orb_ble_send_status(const char *status_json);
```

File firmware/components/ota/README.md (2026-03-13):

# OTA 升级组件

HTTPS 双分区 OTA，支持回滚。

## 接口

```c
esp_err_t orb_ota_init(const orb_ota_config_t *config, orb_ota_event_cb_t event_cb);
esp_err_t orb_ota_check_and_update(void);
```

## 分区方案

使用 ESP-IDF 标准双 OTA 分区：ota_0 / ota_1 交替升级，启动失败自动回滚。

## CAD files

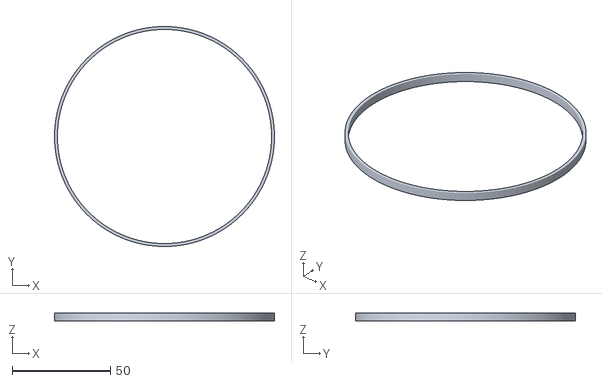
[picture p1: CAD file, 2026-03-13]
hardware/3d_models/orb_v9/exports/orb_v9_led_ring.stl
112.0 x 112.0 x 4.00

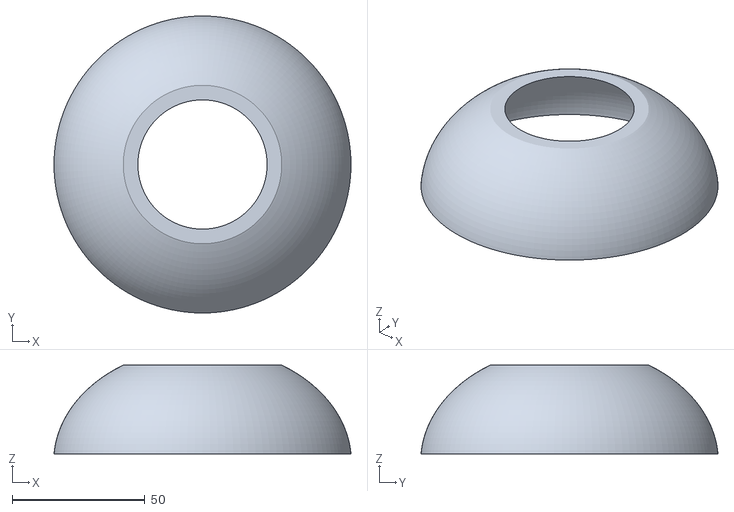
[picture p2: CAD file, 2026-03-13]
hardware/3d_models/orb_v9/exports/orb_v9_Shell_Top.stl
111.7 x 111.7 x 33.4

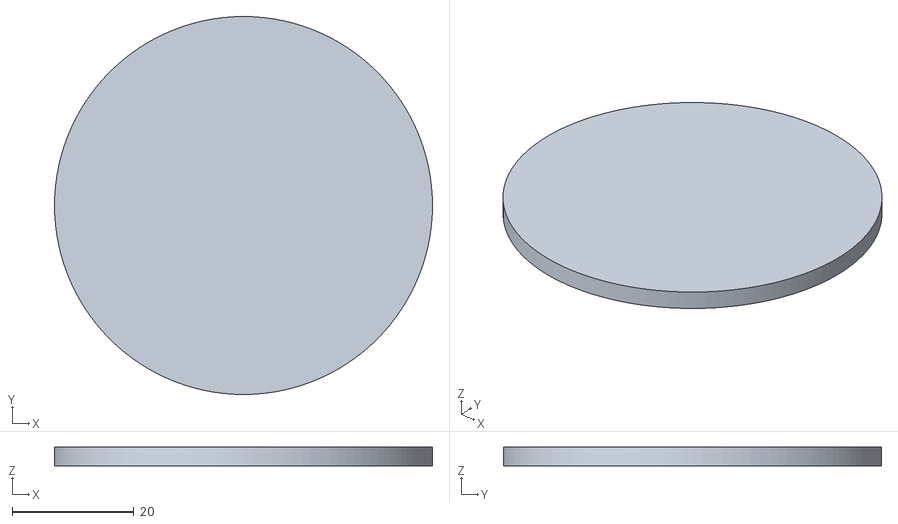
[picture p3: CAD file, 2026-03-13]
hardware/3d_models/orb_v9/exports/orb_v9_base.stl
62.0 x 62.0 x 3.10

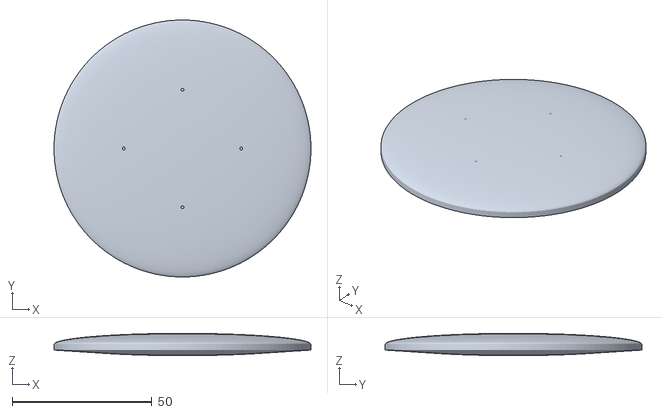
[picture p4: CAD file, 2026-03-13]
hardware/3d_models/orb_v9/exports/orb_v9_top_cap.stl
92.0 x 92.0 x 8.00

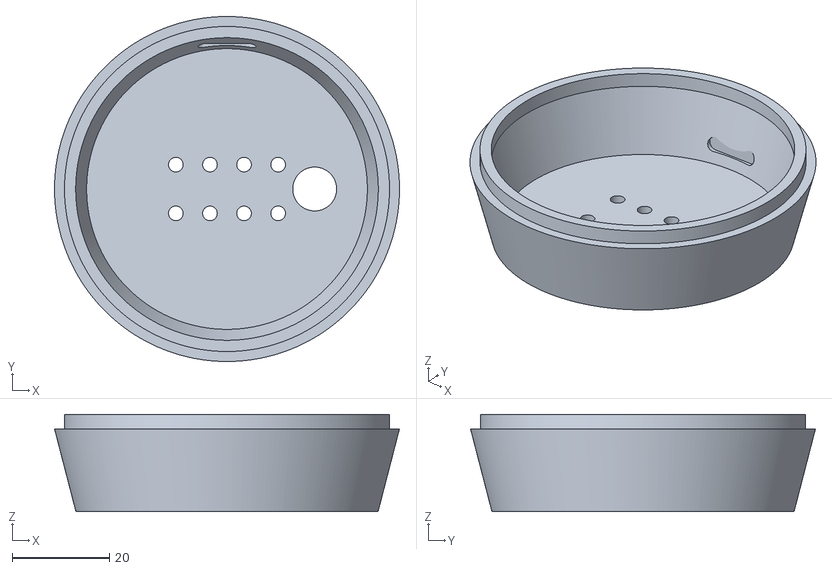
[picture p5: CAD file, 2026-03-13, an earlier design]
hardware/3d_models/orb_v4/exports/bottom.stl
70.8 x 70.8 x 20.0

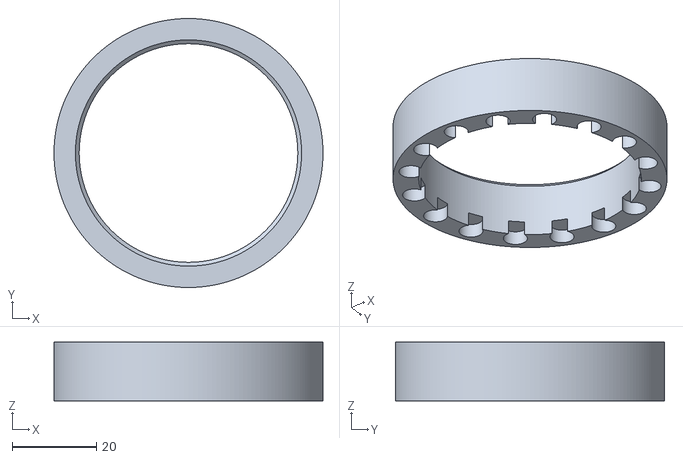
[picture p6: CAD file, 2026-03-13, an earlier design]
hardware/3d_models/orb_v6/exports/lightguide.stl
64.0 x 64.0 x 14.0

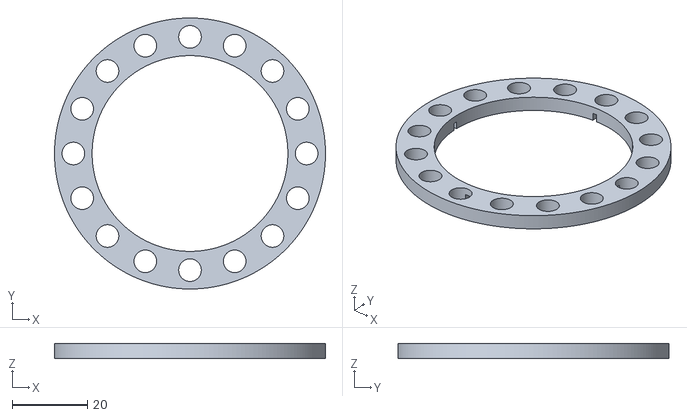
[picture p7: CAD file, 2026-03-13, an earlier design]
hardware/3d_models/orb_v8/exports/led_mount.stl
72.0 x 72.0 x 4.00

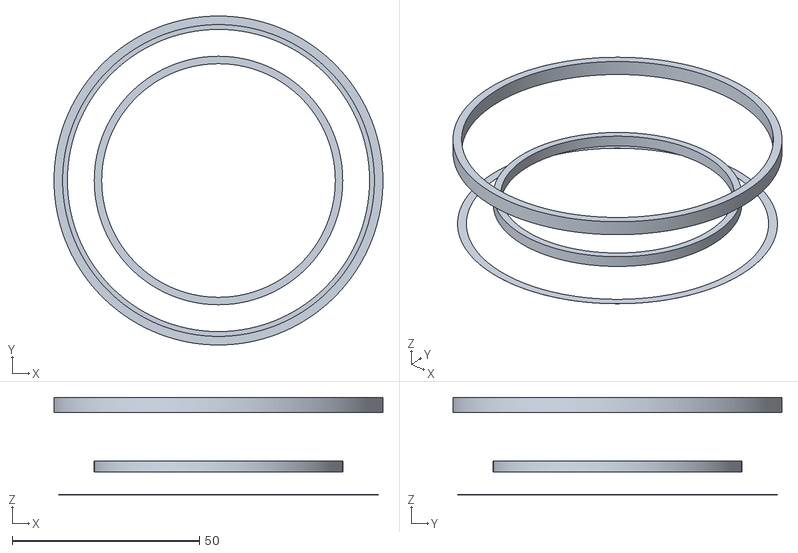
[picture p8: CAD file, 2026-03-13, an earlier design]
hardware/3d_models/orb_v4/exports/mid.stl
87.9 x 87.9 x 26.0

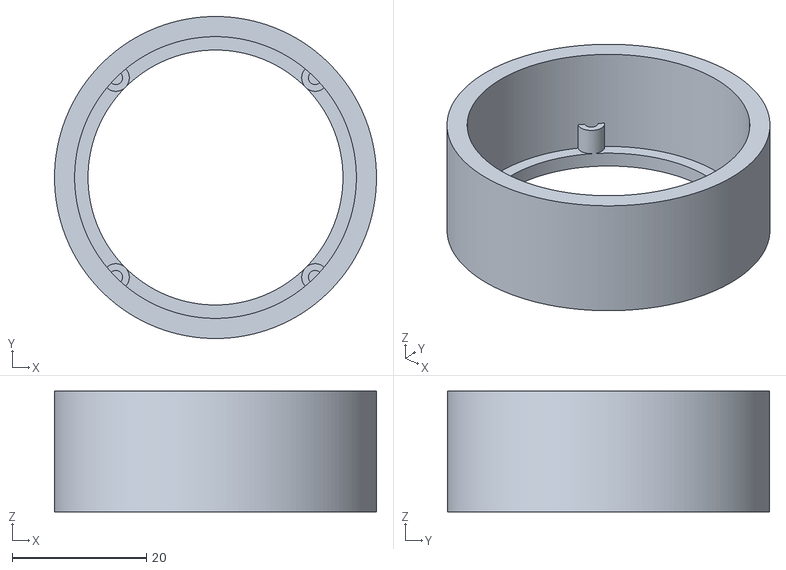
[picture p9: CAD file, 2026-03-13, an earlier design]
hardware/3d_models/orb_v6/exports/acoustic.stl
48.0 x 48.0 x 18.0

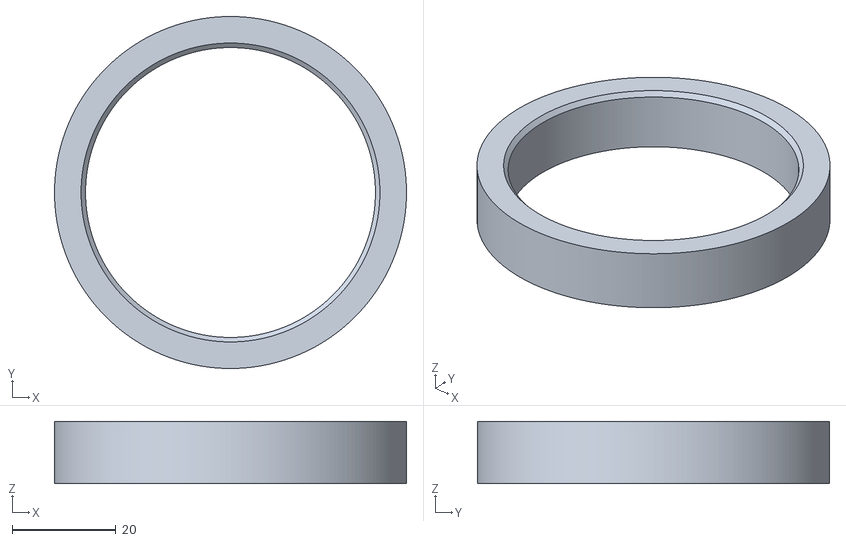
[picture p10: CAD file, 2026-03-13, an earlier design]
hardware/3d_models/orb_v4/exports/lightguide.stl
68.0 x 68.0 x 12.0

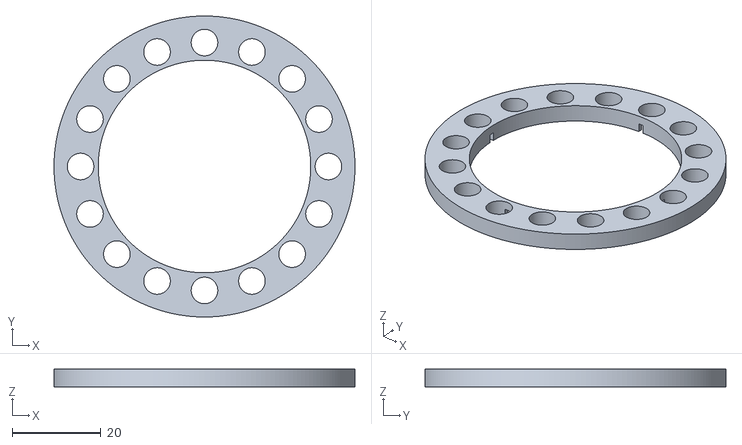
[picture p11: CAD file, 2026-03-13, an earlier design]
hardware/3d_models/orb_v6/exports/led_mount.stl
68.0 x 68.0 x 4.00

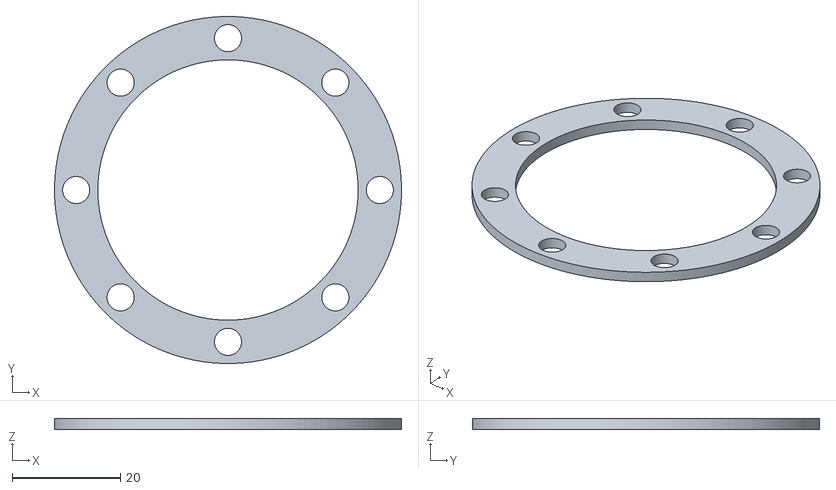
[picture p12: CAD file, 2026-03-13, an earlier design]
hardware/3d_models/orb_v8/exports/halo.stl
64.0 x 64.0 x 2.00

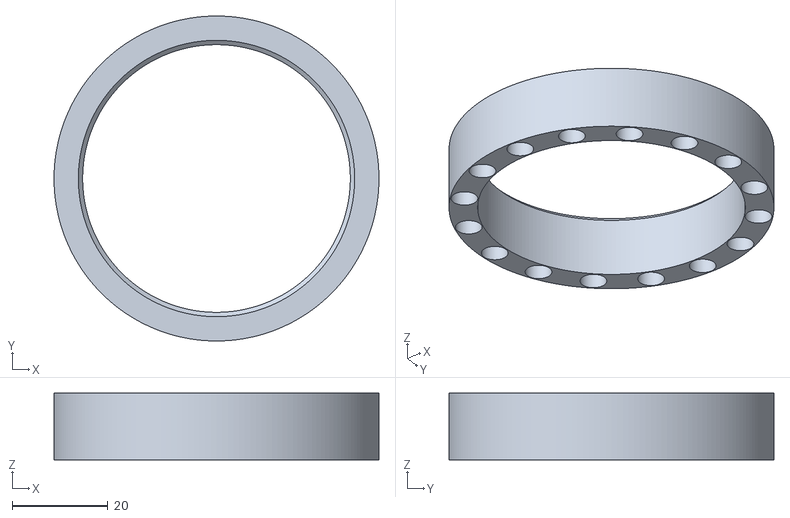
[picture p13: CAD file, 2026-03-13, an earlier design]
hardware/3d_models/orb_v8/exports/lightguide.stl
68.0 x 68.0 x 14.0

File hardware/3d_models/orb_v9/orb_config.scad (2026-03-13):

// ============================================================
// Orb V9 — 全局参数（OpenSCAD 版本）
//
// V9 核心改进（对比 V8）：
//   1. 尺寸: Ø98mm → Ø112mm（桌面更有存在感）
//   2. 曲面: 连续椭球体 (x/56)²+(z/43)²=1，完全无拼接
//   3. 顶盖: 浮岛结构 Ø92mm × 6mm，0.6mm 缝隙呼吸口
//   4. 灯环: 隐藏式 4mm 磨砂扩散罩
//   5. 装配: 5 件式（卡扣 + M2×6 螺丝 ×4）
//
// 比例: H/W = 0.77（蛋形桌面情绪物件）
// ============================================================

// ─── 整机 ─────────────────────────────────────────────────
orb_diameter     = 112;
orb_height       = 86;
rx               = 56;           // 椭球 X 半径
ry               = 43;           // 椭球 Y（Z轴）半径
wall             = 2.2;

// ─── 分割 ─────────────────────────────────────────────────
split_z          = 44;           // 上下壳分割高度
ring_h           = 4;            // 灯环高度
ring_t           = 1.5;          // 灯环壁厚

// ─── 顶盖 ─────────────────────────────────────────────────
cap_d            = 92;           // 浮岛顶盖直径
cap_h            = 6;            // 顶盖厚度
cap_gap          = 0.6;          // 缝隙：麦克风孔 + 灯光溢出
cap_fillet       = 4;            // 顶盖圆角

// ─── 底盖 ─────────────────────────────────────────────────
base_d           = 62;           // 底面直径
base_h           = 3;            // 底盖厚度
base_fillet      = 8;            // 底部圆角

// ─── LED 灯环 ─────────────────────────────────────────────
led_count_main   = 16;           // 主灯环
led_count_halo   = 8;            // 底部 Halo
led_total        = led_count_main + led_count_halo;
led_slot_r       = 2.8;

// ─── 麦克风 ───────────────────────────────────────────────
mic_count        = 4;
mic_spacing      = 42;           // 麦克风间距
mic_hole_d       = 1;
mic_ring_r       = 21;           // 麦克风孔环半径

// ─── PCB ──────────────────────────────────────────────────
pcb_d            = 55;
pcb_thick        = 1.6;

// ─── 装配 ─────────────────────────────────────────────────
screw_d          = 2.2;          // M2 + 间隙
screw_boss_d     = 5;
n_screws         = 4;
screw_ring_r     = 24;

// ─── 渲染精度 ─────────────────────────────────────────────
$fn              = 120;

// ─── 椭球半径函数 ─────────────────────────────────────────
// 给定 z 高度（0..orb_height），返回该高度的截面半径
// 椭球中心在 z=ry，方程: (r/rx)² + ((z-ry)/ry)² = 1
function v9_r(z) =
    let(t = (z - ry) / ry)
    (abs(t) > 1) ? 0 : rx * sqrt(1 - t * t);

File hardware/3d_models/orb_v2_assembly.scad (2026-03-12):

// ============================================================
// Orb V2 — 完整装配体
// AI Companion Orb 工程级结构设计
//
// 用法:
//   F5 预览 → F6 渲染 → 导出 STL
//   修改下方参数自定义尺寸
//   设置 PRINT_PART 可单独导出某个部件
// ============================================================

// --- 全局参数 ---
ORB_RADIUS       = 45;     // 球体外径 90mm
ORB_HEIGHT       = 78;     // 总高度
WALL_THICK       = 2.5;    // 壁厚
BASE_BOTTOM_R    = 30;     // 底面半径 60mm

// --- 打印选择 ---
// 设为 "all" 显示装配体，或设为零件名单独导出
// 可选: "all", "top", "mid", "base"
PRINT_PART = "all";

// --- 爆炸视图 ---
// 设为 0 查看装配状态，>0 查看爆炸视图
EXPLODE = 0;  // 建议值: 0 或 15

// --- 模块引用 ---
use <modules/shell_top.scad>
use <modules/shell_mid.scad>
use <modules/shell_base.scad>
use <modules/led_diffuser.scad>
use <modules/speaker_chamber.scad>
use <modules/pcb_mounts.scad>
use <modules/battery_slot.scad>
use <modules/mic_array.scad>

// ============================================================
// 装配
// ============================================================

module orb_assembly() {
    e = EXPLODE;

    // Layer 1: 上壳（扩散球壳）
    color("White", 0.6)
        translate([0, 0, 55 + e * 4])
            shell_top();

    // Layer 2: LED 扩散腔
    color("Ivory", 0.8)
        translate([0, 0, 40 + e * 3])
            led_diffuser();

    // Layer 3: 主控 PCB 支撑柱
    color("DarkGray")
        translate([0, 0, 30 + e * 2])
            pcb_mounts();

    // Layer 3.5: 麦克风安装座
    color("DimGray")
        translate([0, 0, 30 + e * 2])
            mic_mounts();

    // Layer 4: 中壳
    color("SlateGray", 0.7)
        translate([0, 0, 18 + e * 1])
            shell_mid();

    // Layer 5: 声学共振腔
    color("Gray")
        translate([0, 0, 10 + e * 0.5])
            speaker_chamber();

    // Layer 6: 电池槽
    color("DarkOliveGreen")
        translate([0, 0, 5])
            battery_slot();

    // Layer 7: 底座
    color("DarkSlateGray", 0.9)
        shell_base();
}

// ============================================================
// 渲染控制
// ============================================================

if (PRINT_PART == "all") {
    orb_assembly();
} else if (PRINT_PART == "top") {
    shell_top();
} else if (PRINT_PART == "mid") {
    shell_mid();
} else if (PRINT_PART == "base") {
    shell_base();
}

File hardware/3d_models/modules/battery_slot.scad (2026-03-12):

// ============================================================
// Orb V2 — 电池槽（18650 单节）
// ============================================================

// --- 参数 ---
bat_diameter  = 18;      // 18650 直径
bat_length    = 65;      // 18650 长度
slot_padding  = 1;       // 槽壁间隙
slot_wall     = 1.5;     // 槽壁厚度

slot_w = bat_diameter + slot_padding * 2 + slot_wall * 2;   // ~22mm
slot_l = bat_length + slot_padding * 2 + slot_wall * 2;     // ~71mm
slot_h = bat_diameter / 2 + slot_padding + slot_wall;        // ~12.5mm

module battery_slot() {
    difference() {
        // 外壳
        translate([-slot_w / 2, -slot_l / 2, 0])
            cube([slot_w, slot_l, slot_h]);

        // 电池腔（圆柱形底部）
        translate([0, 0, slot_h])
            rotate([90, 0, 0])
                translate([0, 0, -bat_length / 2 - slot_padding])
                    cylinder(h = bat_length + slot_padding * 2,
                             r = bat_diameter / 2 + slot_padding, $fn = 40);

        // 导线槽
        translate([0, slot_l / 2 - slot_wall, slot_h / 2])
            cube([4, slot_wall * 2 + 0.2, slot_h], center = true);
        translate([0, -(slot_l / 2 - slot_wall), slot_h / 2])
            cube([4, slot_wall * 2 + 0.2, slot_h], center = true);
    }

    // 弹簧触片凸台
    translate([0, -slot_l / 2 + slot_wall, 0])
        cylinder(h = slot_h - bat_diameter / 4, r = 3, $fn = 16);
}

battery_slot();

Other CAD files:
hardware/3d_models/orb_v8/exports/acoustic.stl
hardware/3d_models/modules/led_diffuser.scad
hardware/3d_models/modules/mic_array.scad
hardware/3d_models/modules/pcb_mounts.scad
hardware/3d_models/modules/shell_base.scad
hardware/3d_models/modules/shell_mid.scad
hardware/3d_models/modules/shell_top.scad
hardware/3d_models/modules/speaker_chamber.scad
hardware/3d_models/orb_v4/orb_acoustic.scad
hardware/3d_models/orb_v4/orb_assembly.scad
hardware/3d_models/orb_v4/orb_battery.scad
hardware/3d_models/orb_v4/orb_config.scad
hardware/3d_models/orb_v4/orb_led_mount.scad
hardware/3d_models/orb_v4/orb_lightguide.scad
hardware/3d_models/orb_v4/orb_mic_array.scad
hardware/3d_models/orb_v4/orb_pcb_mount.scad
hardware/3d_models/orb_v4/orb_shell_bottom.scad
hardware/3d_models/orb_v4/orb_shell_middle.scad
hardware/3d_models/orb_v4/orb_shell_top.scad
hardware/3d_models/orb_v6/orb_acoustic.scad
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

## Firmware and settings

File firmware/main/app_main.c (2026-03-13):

/**
 * AI Companion Orb — 主程序入口
 *
 * 职责：初始化所有组件 + 事件调度
 * 业务逻辑不在此文件中实现
 *
 * 硬件：V8 PCB — ESP32-S3 + 24× WS2812B + 4× INMP441 + MAX98357A
 *              + BME280 + MPU6050（I2C） + 3 区电容触摸
 * GPIO 定义：firmware/main/include/orb_pins.h
 */

#include <stdio.h>
#include <string.h>
#include "freertos/FreeRTOS.h"
#include "freertos/task.h"
#include "esp_log.h"
#include "nvs_flash.h"
#include "orb_pins.h"

#include "orb_led.h"
#include "orb_touch.h"
#include "orb_audio.h"
#include "orb_wifi.h"
#include "orb_ble.h"
#include "orb_ota.h"
#include "orb_sensor.h"    // BME280 + MPU6050 via I2C GPIO8/9

static const char *TAG = "orb_main";

/* ── Default OTA server URL — must be overridden before production build ── */
#ifndef OTA_SERVER_URL
#define OTA_SERVER_URL "https://ota.example.com/orb/firmware.bin"
#endif

/* ── Component callbacks ────────────────────────────────────────────────── */

static void on_touch_event(const orb_touch_event_t *event)
{
    ESP_LOGI(TAG, "Touch: gesture=%d area=%.2f duration=%" PRIu32 "ms",
             event->gesture, event->touch_area, event->duration_ms);

    switch (event->gesture) {
        case TOUCH_TAP:
            orb_led_set_mood(ORB_MOOD_TOUCH_RESPONSE);
            break;
        case TOUCH_LONG:
            /* Long press → enter conversation / listening mode */
            orb_led_set_mood(ORB_MOOD_LISTENING);
            break;
        case TOUCH_EMBRACE:
            /* Embrace → calming comfort animation */
            orb_led_set_mood(ORB_MOOD_CALM);
            break;
        case TOUCH_DOUBLE_TAP:
            /* Double-tap → pause / resume, return to idle */
            orb_led_set_mood(ORB_MOOD_IDLE);
            break;
        default:
            break;
    }
}

static void on_wifi_event(orb_wifi_state_t state, const char *ip)
{
    switch (state) {
        case WIFI_STATE_CONNECTING:
            ESP_LOGI(TAG, "WiFi connecting...");
            orb_led_set_mood(ORB_MOOD_THINKING);
            break;
        case WIFI_STATE_CONNECTED:
            ESP_LOGI(TAG, "WiFi connected — IP: %s", ip ? ip : "unknown");
            orb_led_set_mood(ORB_MOOD_OK);
            break;
        case WIFI_STATE_DISCONNECTED:
            ESP_LOGW(TAG, "WiFi disconnected");
            orb_led_set_mood(ORB_MOOD_IDLE);
            break;
        case WIFI_STATE_FAILED:
            ESP_LOGE(TAG, "WiFi connection failed");
            orb_led_set_mood(ORB_MOOD_ALERT);
            break;
        default:
            break;
    }
}

static void on_ble_provision(const char *ssid, const char *password)
{
    ESP_LOGI(TAG, "BLE provisioning received — SSID: %s", ssid);

    orb_wifi_config_t wifi_cfg;
    memset(&wifi_cfg, 0, sizeof(wifi_cfg));
    strlcpy(wifi_cfg.ssid,     ssid,     sizeof(wifi_cfg.ssid));
    strlcpy(wifi_cfg.password, password, sizeof(wifi_cfg.password));

    esp_err_t err = orb_wifi_connect(&wifi_cfg);
    if (err != ESP_OK) {
        ESP_LOGE(TAG, "orb_wifi_connect failed: %s", esp_err_to_name(err));
    }
}

static void on_audio_data(const int16_t *samples, size_t count)
{
    /* Hand off to the backend WebSocket pipeline (not yet implemented). */
    ESP_LOGD(TAG, "Audio chunk received: %zu samples", count);
}

static void on_ota_event(orb_ota_state_t state, int pct)
{
    switch (state) {
        case OTA_STATE_CHECKING:
            ESP_LOGI(TAG, "OTA: checking for update");
            break;
        case OTA_STATE_DOWNLOADING:
            ESP_LOGI(TAG, "OTA: downloading %d%%", pct);
            orb_led_set_mood(ORB_MOOD_THINKING);
            break;
        case OTA_STATE_VERIFYING:
            ESP_LOGI(TAG, "OTA: verifying image");
            break;
        case OTA_STATE_REBOOTING:
            ESP_LOGI(TAG, "OTA: update complete — rebooting");
            orb_led_set_mood(ORB_MOOD_OK);
            break;
        case OTA_STATE_FAILED:
            ESP_LOGE(TAG, "OTA: update failed");
            orb_led_set_mood(ORB_MOOD_ALERT);
            break;
        default:
            break;
    }
}

/* ── Entry point ────────────────────────────────────────────────────────── */

void app_main(void)
{
    ESP_LOGI(TAG, "=== AI Companion Orb v0.1 ===");
    ESP_LOGI(TAG, "硬件: V8 PCB  LED_DIN=GPIO%d  MIC_BCLK=GPIO%d  I2C_SDA=GPIO%d",
             ORB_PIN_LED_DIN, ORB_PIN_I2S_MIC_BCLK, ORB_PIN_I2C_SDA);

    /* ── NVS flash (required by WiFi, BLE, OTA) ─────────────────────── */
    esp_err_t ret = nvs_flash_init();
    if (ret == ESP_ERR_NVS_NO_FREE_PAGES || ret == ESP_ERR_NVS_NEW_VERSION_FOUND) {
        ESP_ERROR_CHECK(nvs_flash_erase());
        ret = nvs_flash_init();
    }
    ESP_ERROR_CHECK(ret);

    /* ── LED engine — first up so the Orb looks "alive" immediately ──── */
    orb_led_config_t led_cfg = {
        .gpio_num  = ORB_LED_DEFAULT_GPIO,
        .led_count = ORB_LED_COUNT,
    };
    ESP_ERROR_CHECK(orb_led_init(&led_cfg));
    ESP_ERROR_CHECK(orb_led_set_mood(ORB_MOOD_IDLE));

    /* ── Touch sensor ───────────────────────────────────────────────── */
    orb_touch_config_t touch_cfg = {
        .callback             = on_touch_event,
        .long_press_ms        = 1500,
        .embrace_ms           = 3000,
        .double_tap_window_ms = 300,
    };
    ESP_ERROR_CHECK(orb_touch_init(&touch_cfg));

    /* ── Audio — I2S mic + speaker, default GPIO assignments ─────────── */
    orb_audio_config_t audio_cfg = {
        .mic_bck_io  = AUDIO_MIC_BCK_GPIO,
        .mic_ws_io   = AUDIO_MIC_WS_GPIO,
        .mic_data_io = AUDIO_MIC_DATA_GPIO,
        .spk_bck_io  = AUDIO_SPK_BCK_GPIO,
        .spk_ws_io   = AUDIO_SPK_WS_GPIO,
        .spk_data_io = AUDIO_SPK_DATA_GPIO,
    };
    ESP_ERROR_CHECK(orb_audio_init(&audio_cfg));

    /* ── WiFi manager — auto-connects if NVS credentials exist ──────── */
    ESP_ERROR_CHECK(orb_wifi_init(on_wifi_event));

    /* ── BLE provisioning — advertise so App can push WiFi credentials ─ */
    ESP_ERROR_CHECK(orb_ble_init(on_ble_provision));
    if (!orb_wifi_is_connected()) {
        ESP_LOGI(TAG, "No saved WiFi config — starting BLE advertising");
        ESP_ERROR_CHECK(orb_ble_start_advertising());
        orb_led_set_mood(ORB_MOOD_CALM); /* Blue breathing = waiting for setup */
    }

    /* ── OTA — periodic background update checks ─────────────────────── */
    orb_ota_config_t ota_cfg = {
        .check_interval_ms = OTA_CHECK_INTERVAL_MS,
        .firmware_version  = OTA_FIRMWARE_VERSION,
        /* cert_pem: set to embedded PEM before production deployment.
         * See orb_ota_config_t.cert_pem documentation in orb_ota.h. */
        .cert_pem          = NULL,
    };
    strlcpy(ota_cfg.server_url, OTA_SERVER_URL, sizeof(ota_cfg.server_url));
    ESP_ERROR_CHECK(orb_ota_init(&ota_cfg, on_ota_event));

    /* ── Ready ───────────────────────────────────────────────────────── */
    ESP_LOGI(TAG, "=== AI Companion Orb v%s ===", orb_ota_get_running_version());
    ESP_LOGI(TAG, "有温度的家庭 IoT — 设备就绪");

    /* Main loop — components are event-driven; nothing to poll here. */
    while (1) {
        vTaskDelay(pdMS_TO_TICKS(1000));
    }
}

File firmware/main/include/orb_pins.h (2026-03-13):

/**
 * @file orb_pins.h
 * @brief AI Companion Orb V8 — GPIO 引脚定义（中央定义文件）
 *
 * 所有固件组件通过此头文件获取引脚编号，不允许在组件内硬编码 GPIO。
 * 引脚来源：V8 PCB 原理图（hardware/pcb/README.md）
 */

#pragma once

// ─────────────────────────────────────────────
// LED 驱动（RMT，WS2812B）
// ─────────────────────────────────────────────
#define ORB_PIN_LED_DIN         18   ///< 主灯环 + Halo 菊链 DIN（串 330Ω）
#define ORB_LED_MAIN_COUNT      16   ///< 主灯环 WS2812B 颗数
#define ORB_LED_HALO_COUNT       8   ///< 底部 Halo WS2812B 颗数
#define ORB_LED_TOTAL_COUNT     24   ///< 总颗数（主环 + Halo）

// ─────────────────────────────────────────────
// I2S 麦克风（4× INMP441，90° 环形阵列）
// ─────────────────────────────────────────────
#define ORB_PIN_I2S_MIC_BCLK     4   ///< Bit Clock
#define ORB_PIN_I2S_MIC_LRCK     5   ///< Left/Right Clock
#define ORB_PIN_I2S_MIC_DATA     6   ///< Data（4 路并联，L/R 分时复用）
#define ORB_MIC_COUNT            4   ///< 麦克风数量

// ─────────────────────────────────────────────
// I2S 扬声器（MAX98357A）— 独立 I2S 总线
// ─────────────────────────────────────────────
#define ORB_PIN_I2S_SPK_BCLK     1   ///< Bit Clock
#define ORB_PIN_I2S_SPK_LRC      2   ///< Left/Right Clock
#define ORB_PIN_I2S_SPK_DIN      3   ///< Data Input

// ─────────────────────────────────────────────
// I2C 传感器总线（BME280 + MPU6050）
// ─────────────────────────────────────────────
#define ORB_PIN_I2C_SDA          8   ///< SDA (4.7kΩ 上拉至 3.3V)
#define ORB_PIN_I2C_SCL          9   ///< SCL (4.7kΩ 上拉至 3.3V)

// I2C 设备地址
#define ORB_I2C_ADDR_BME280   0x76   ///< BME280 SDO=GND → 0x76
#define ORB_I2C_ADDR_MPU6050  0x68   ///< MPU6050 AD0=GND → 0x68

// ─────────────────────────────────────────────
// 触摸（ESP32-S3 内置电容触摸控制器）
// 具体通道号待测试板确认后在此更新
// ─────────────────────────────────────────────
#define ORB_TOUCH_TOP_CH         1   ///< 顶部触摸区
#define ORB_TOUCH_MID_CH         2   ///< 中部触摸区
#define ORB_TOUCH_BOT_CH         3   ///< 底部触摸区

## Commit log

2026-03-12 🔮 init: AI Companion Orb 项目骨架
    - firmware/: ESP32-S3 固件 (ESP-IDF, 6个组件目录)
    - app/: Flutter App (Feature-first 结构)
    - backend/: Python FastAPI 后端
    - hardware/: 3D模型 + PCB + BOM
    - CLAUDE.md: 完整架构指南 (含灯光/触摸/音频/API/安全规格)
    - docs/SPARK-使用指南.md: AI编程代理任务队列
    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
2026-03-12 feat(firmware): implement led_engine component (WS2812B via RMT)
    - Add CMakeLists.txt registering orb_led.c with driver + esp_timer deps
    - Add include/orb_led.h: orb_mood_t (9 moods), orb_rgb_t, orb_led_config_t,
    full public API (init/set_mood/set_brightness/set_color/deinit)
    - Add orb_led.c: complete ESP-IDF v5.2 RMT implementation
    - Custom ws2812_encoder (bytes + copy encoder, WS2812B timing T0H=300ns etc.)
    - FreeRTOS animation task at priority 5, 50 fps (20 ms tick)
    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
2026-03-12 fix(led_engine): address code review feedback
    - ANIM_ROTATE: use period_ticks/led_count to pace rotation correctly so
    one full revolution takes BREATH_PERIOD_MS (3.5 s) instead of being
    tied to raw frame count
    - render_frame: track s_current_base (unscaled) after every animation
    branch so the cross-fade origin is never brightness-corrupted
    - orb_led_set_mood: read s_current_base (not raw GRB pixel bytes) as the
    cross-fade start colour, avoiding hue drift caused by brightness scaling
    - orb_led_set_color / orb_led_init: initialise / update s_current_base
    [orb_led.c]
2026-03-12 feat(firmware): implement touch_sensor component with FSM gesture detection
    - Add orb_touch.h: public API with touch_gesture_t enum, orb_touch_event_t
    struct, orb_touch_config_t and the three public functions
    - Add orb_touch.c: full ESP-IDF touch driver implementation
    - Configures TOUCH_PAD_NUM1/2/3 (top/mid/bot sphere zones)
    - Voltage: HVOLT_2V7 / LVOLT_0V5 / HVOLT_ATTEN_1V for 85 mm sphere
    - 4-state FSM: IDLE → DEBOUNCE → TOUCHED → AWAIT_SECOND
    - Gestures: TAP (<300 ms), LONG (>1500 ms), EMBRACE (multi-pad >3000 ms),
    DOUBLE_TAP (two taps within 300 ms window)
    - 50 ms debounce to suppress noise
    - touch_area reported as 0.33 / 0.66 / 1.0 (fraction of active pads)
    -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
2026-03-12 feat(firmware): implement audio pipeline component (I2S + VAD)
    - Add CMakeLists.txt registering component with driver/esp_timer/freertos
    - Add orb_audio.h with constants, enums, config struct and full public API
    - Add orb_audio.c with ESP-IDF v5 I2S driver (i2s_new_channel /
    i2s_channel_init_std_mode), RMS-based VAD recording task that
    auto-stops after 1.5 s silence, software volume scaling, and
    mutex-guarded IDLE/LISTENING/PLAYING state machine
    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
2026-03-12 feat(ota): implement OTA component and wire all components in app_main
    - Add firmware/components/ota/ with CMakeLists.txt, orb_ota.h, orb_ota.c,
    and README.md
    - OTA uses esp_https_ota for secure download over HTTPS
    - Dual A/B partition scheme via esp_ota_get_next_update_partition()
    - First-boot rollback confirmation via esp_ota_mark_app_valid_cancel_rollback()
    - Periodic background checks via esp_timer (default 1 h interval)
    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
2026-03-12 feat(backend): implement complete FastAPI backend for AI Companion Orb
    - config.py: Pydantic Settings for all env vars
    - database.py: async SQLAlchemy engine + Redis client with DI helpers
    - models: User, Device, ConversationSession, Message, Alert (SQLAlchemy)
    - schemas: Pydantic request/response models for all routes
    - services: LLMGateway (DashScope→DeepSeek fallback, streaming), SafetyClassifier
    (keyword+regex self-harm detection), MemoryService (Redis sliding window),
    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
2026-03-12 feat(hardware): Orb V2+V4 3D结构设计
    V2 原型结构 (hardware/3d_models/modules/):
    - 8个OpenSCAD模块: 外壳/扩散腔/声学腔/PCB支撑/电池槽/麦克风
    - Ø90×H78mm, 24×WS2812B, 扩散腔光学
    V4 量产级结构 (hardware/3d_models/orb_v4/):
    - 11个OpenSCAD模块, 参数化全局配置
    - 工业比例 Ø92×H75mm (黄金比例0.82)
    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
    [battery_slot.scad, led_diffuser.scad, mic_array.scad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]
2026-03-13 feat(hardware): Orb V6 工业级结构设计 + 一键导出
    V6 核心改进（消除灯泡感）：
    - 上壳改用扁椭球 scale([1,1,0.826])，rx=ry=46 rz=38
    - 中框腰线收窄（最细处 Ø74mm），贝塞尔曲率过渡
    - 底座喇叭口倒圆角 hull()，三段曲率连续
    结构升级：
    - LED 16颗（成本优化），4麦阵列 INMP441
    - 底座电池管立柱，倒相管内置 Ø8×14mm
    - USB-C 椭圆形开口，声孔环形阵列
    - PCB 螺丝柱 4点均布（M2.5）
    工程：
    - 8 模块文件完整参数化
    - export_stl.sh 一键导出全部 STL
    - 6/6 STL 全部 Simple=yes（无非流形）
    - V4 lightguide 非流形修复
    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
    [acoustic.stl, bottom.stl, led_mount.stl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]
2026-03-13 feat(hardware): Orb V8 苹果级产品设计
    核心设计（对比 V6 灯泡 → V8 鹅卵石）：
    - 比例 H/W=0.69（98×68mm），视觉重心下移 equator=44%
    - 双段参数曲线：底部幂函数(t^0.65) + 顶部椭圆弧
    - 效果：R40底→R90腹→R60顶，三段曲率连续
    - 新增底部光晕系统（8颗 WS2812B，桌面漫射光）
    结构：
    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
    [acoustic.stl, halo.stl, led_mount.stl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]
2026-03-13 feat(pcb+firmware): V8 PCB架构落地 — GPIO定义/传感器组件/PCB文档
    - CLAUDE.md: 外形 85mm→Ø98mm×H68mm V8，LED 12→16+8 Halo，
    麦克风 3→4，新增硬件规格表/GPIO引脚表/传感器章节/V8决策记录
    - firmware/main/include/orb_pins.h: 新建中央GPIO定义头文件
    (LED=GPIO18, MicI2S=GPIO4/5/6, SpkI2S=GPIO1/2/3, I2C=GPIO8/9)
    - firmware/components/sensor: 新建环境传感器组件骨架
    (BME280 + MPU6050, I2C, orb_sensor.h 接口定义)
    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
2026-03-13 docs(app): 新增 Orb App 设计规范与开发指南
2026-03-13 feat(3d): Orb V9 工业设计级建模 — 连续椭球体 + 浮岛顶盖
    V9 核心设计（Ø112mm × H86mm，H/W=0.77 蛋形桌面情绪物件）：
    - 连续椭球体 (x/56)²+(z/43)²=1，完全消除拼接感
    - 浮岛式顶盖 Ø92mm，0.6mm 缝隙兼做麦克风孔和灯光溢出口
    - 隐藏式灯环 4mm 磨砂 PC 扩散罩，光从内部自然透出
    - 5 件式装配：顶盖/上壳/灯环/下壳/底盖（M2×6 ×4）
    - FreeCAD Python 参数化脚本 + OpenSCAD 双版本
    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
    [orb_assembly.scad, orb_base.scad, orb_config.scad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]
2026-03-13 feat(app): Build complete Flutter app for AI Companion Orb
    Creates full runnable Flutter app from scratch, replacing all placeholder
    .gitkeep files with ~4700 lines of production-quality Dart code.
    ## Structure
    - pubspec.yaml with flutter_riverpod, go_router, fl_chart, shimmer
    - analysis_options.yaml with flutter_lints
    - lib/main.dart: entry with ProviderScope, orientation lock, system UI
    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
2026-03-13 feat(app): Complete Flutter UI implementation for AI Companion Orb
    - Full Flutter project structure (pubspec.yaml, analysis_options.yaml)
    - Core theme tokens: OrbColors (7 emotion × dark BG), OrbTypography, OrbSpacing, OrbAnimation
    - OrbSphere: CustomPainter breathing orb (scale 0.95→1.05, 4s ease-in-out) with emotion color transitions
    - 4-tab navigation via go_router StatefulShellRoute (Orb Home / Chat / Memory / Settings)
    - OrbHomePage: immersive dark background with animated orb, AI greeting, memory snippets, emotion selector
    - ChatPage: emotion-reactive chat bubbles, typing dots, emotion transition overlay
    - MemoryPage: Bento grid layout, emotion filter chips, detail view
    - SettingsPa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
2026-03-13 fix: resolve Flutter 3.16 compatibility issues in app
    - pubspec.yaml: lower SDK constraint to >=3.2.0, pin record ^5.0.5,
    web_socket_channel ^2.3.0, riverpod_generator ^2.3.10 for Dart 3.2.6
    - delete core/app.dart and core/router.dart (stale files from second branch)
    - orb_theme.dart: CardThemeData→CardTheme, WidgetStateProperty→MaterialStateProperty
    - orb_app_bar.dart / orb_bottom_nav.dart: fix import path ../../core → ../../../core
    - chat_bubble.dart, memory_card.dart, family_care_page.dart, memory_detail_page.dart:
    add missing orb_emotion.dart import for extension method visibility
    - orb_bottom_nav.dart: reduce padding/icon size to fix 3px Column overflow in tests
    - all 2 widget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
